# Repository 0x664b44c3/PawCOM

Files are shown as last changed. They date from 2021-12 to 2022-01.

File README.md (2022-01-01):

# PawCOM - a Partyline Analog (Wired) intercom system

## Scope of this project
This projects implements a partyline analog intercom system as used in the tv and event industry for interconnecting small teams of technical staff.

The system consists of any number from 2 up of so-called beltpacks, portable intercom stations plus a central power supply.
The portable parts are interconnected by generic microphone cabling (industry standard) and is electrically compatible to ClearCom, RTS and others.
Analog circuitry was inspired by the classic ClearCom MR102 and others but has been re-engineered from the ground up to use modern components and
add a few extra features.

## PAWCOM features

- analog signal processing with digital control
  - latency free
  - compressor/limiter on mic channel
  - limiter in Rx audio path (your ears will love you)
  - digitally adjustable sidetone level
  - adjustable MIC gain
  - low background noise
- Digital volume control
- digital PTT control with both latching and push to talk mode
- switchable mic power for electred mic headsets
- stereo headphone amp
- optional line in for program audio or personal music player

- click/pop free Call function
  - automatic audible call function if call is held for a certain time

## Circuit description

The beltpack consists of six main components:

- Line receiver 
- Audio mixer and headphone Amp
- Mic preamp and Line driver
- Sidetone Adjust
- Call circuitry
- System control MCU

### Line receiver
The line receiver is based around a quad opamp TL074. One gate implements the line receiver, one gate buffers the sidetone signal, the third gate generates VCC/2 (AGND) which is used througout the line interface. The last gate is unused (connected as a voltage follower with AGND on its input).

### Sidetone circuitry
Sidetone processing is located between the mic preamp (see below) and the line driver.
The sidetone signal is taken from the output of the mic preamp after the tx switch. 
It is then routed through a digital potentiometer MAX5395 and routed through the third opamp of the TL074 were its common mode voltage is translated to AGND (V+/2),
 routed through a passive filter that tries to mimic a typical line impedance, and is then applied to the inverted input of the line receiver OPAMP.

### Mic preamp and Tx switch

The mic preamp is based around an NJM2783 integrated mic preamp that includes
both preamp, switchable gain, a compressor and a buffer amplifier. The mic preamp is powered by a +9V rail generated by a LMR64010 boost converter from the +5V bus (optional, should lower the noise figure of the NJM2783 plus provide a bit more pre-compressor headroom).
The signal is then routed through a TS5A9411 analog switch (capacitive coupling is used here to bring the common mode voltage down to 2.5V) to provide a switchable  additional -10dB pad and then goes into gate 1 of an LMV358 driving 
into the MAX5359 sidetone-digipot.

The Tx signal then goes through a NE5534 driving the signal line. A last bit of filtering is applied here to provide a roll of towards higher frequencies and then driven onto the line through coupling capacitor and a 1.5kΩ resistor.

### Audio mixer

The actual audio mixer section consists of two LMV324 quad-opamps, a DS1881 digital volume control and a NJM2762 compressor/limiter IC.

The signal from the line receiver is goes through the NJM2762 compressor/limiter
and into a TS5A9411 analog switch (line mute).
The signal is then routed through a first buffer stage (gain = 6dB)
and then mixed with the beep signal from the MCU.
This stage drives onto two passive mixers/adders formed by resistor networks
that also provide a place to insert a stereo "program audio" signal into the headphones. This sum-signal is then buffered by two more LMV324 gates and drives the two halves of the DS1881 digital volume control IC.
The output signal of this digipot is buffered once more by two further opamps connected as voltage followers and then finally goes into the headphone amplifier.

### Headphone amplifier

The headphone amplifier is based around a LM4880 stereo amplifier. Currently no
further gain is applied in this stage.
The output goes through two coupling capacitors (100µ electrolytic) and then out to the headset connector. The pins on the headset connector are also connected to ground by 22kΩ resistors to allow the circuitry to reach steady state without connected headphone. This helps to avoid loud clicks upon connection the headset.

### Call circuitry

The call circuitry consists of two parts: call driver and call detector.
The call driver is based around two transistors applying a slew-rate limited, current-limited drive to the signal line of the cable.
Call detection is accomplished by a schmitt trigger built around another gate of a LMV324 with a threshold of roughly 2.5V.

### System controller

An ATMega324PB handles all control tasks in the beltpack. It includes UI (rotary encoder, PTT and call button, a few LEDs), beep tone generation and so on.
Furthermore the uC has one ADC dedicated to monitoring the supply voltage of the beltpack to detect a mic mute pulse as used by some systems.

The digital pots are controlled using an I2C bus that also routes to the front panel (where a PCF8574 port expander takes car eof driving the LEDs and rading PTT and call button status).

## Further reading and other projects about Partyline

You may have a look at the fnordcom project that has compiled a number of schematics and information around
older clearcom intercom systems: https://github.com/pc-coholic/fnordcom

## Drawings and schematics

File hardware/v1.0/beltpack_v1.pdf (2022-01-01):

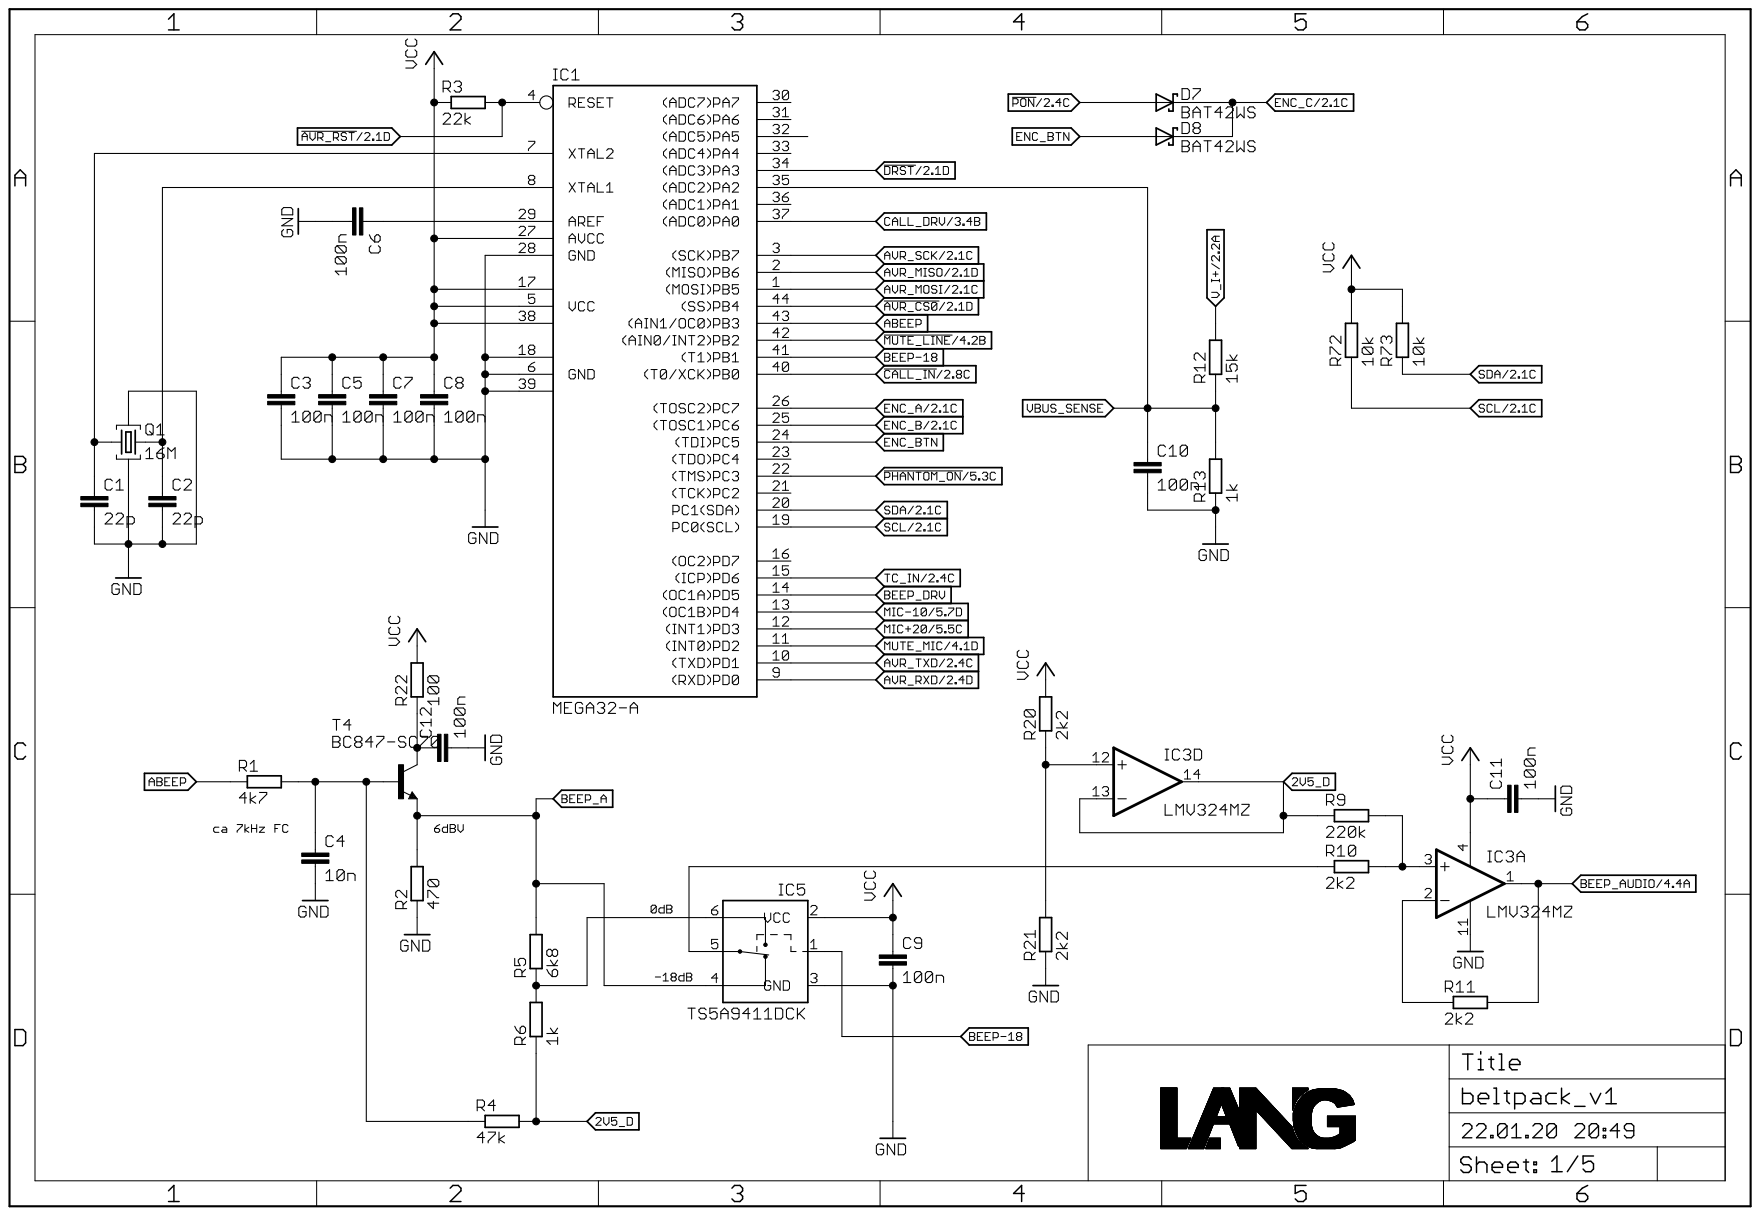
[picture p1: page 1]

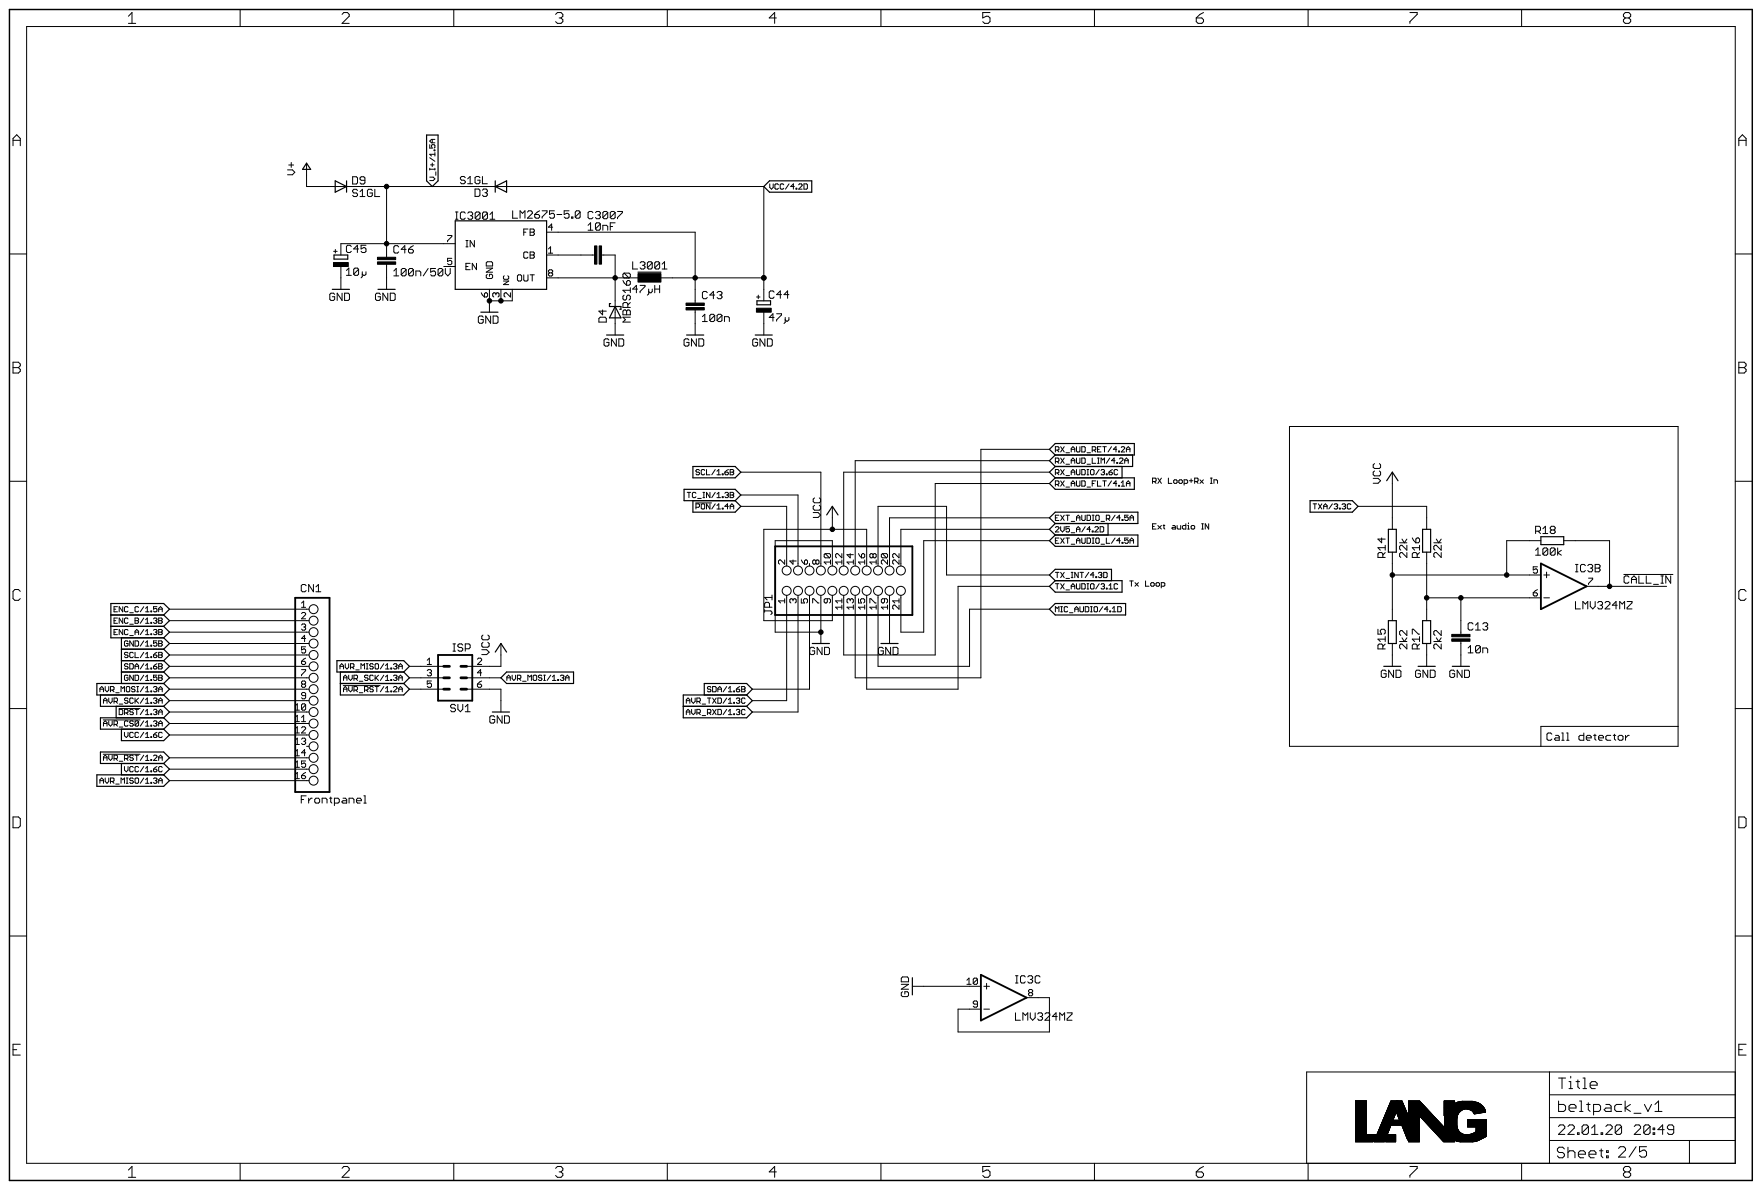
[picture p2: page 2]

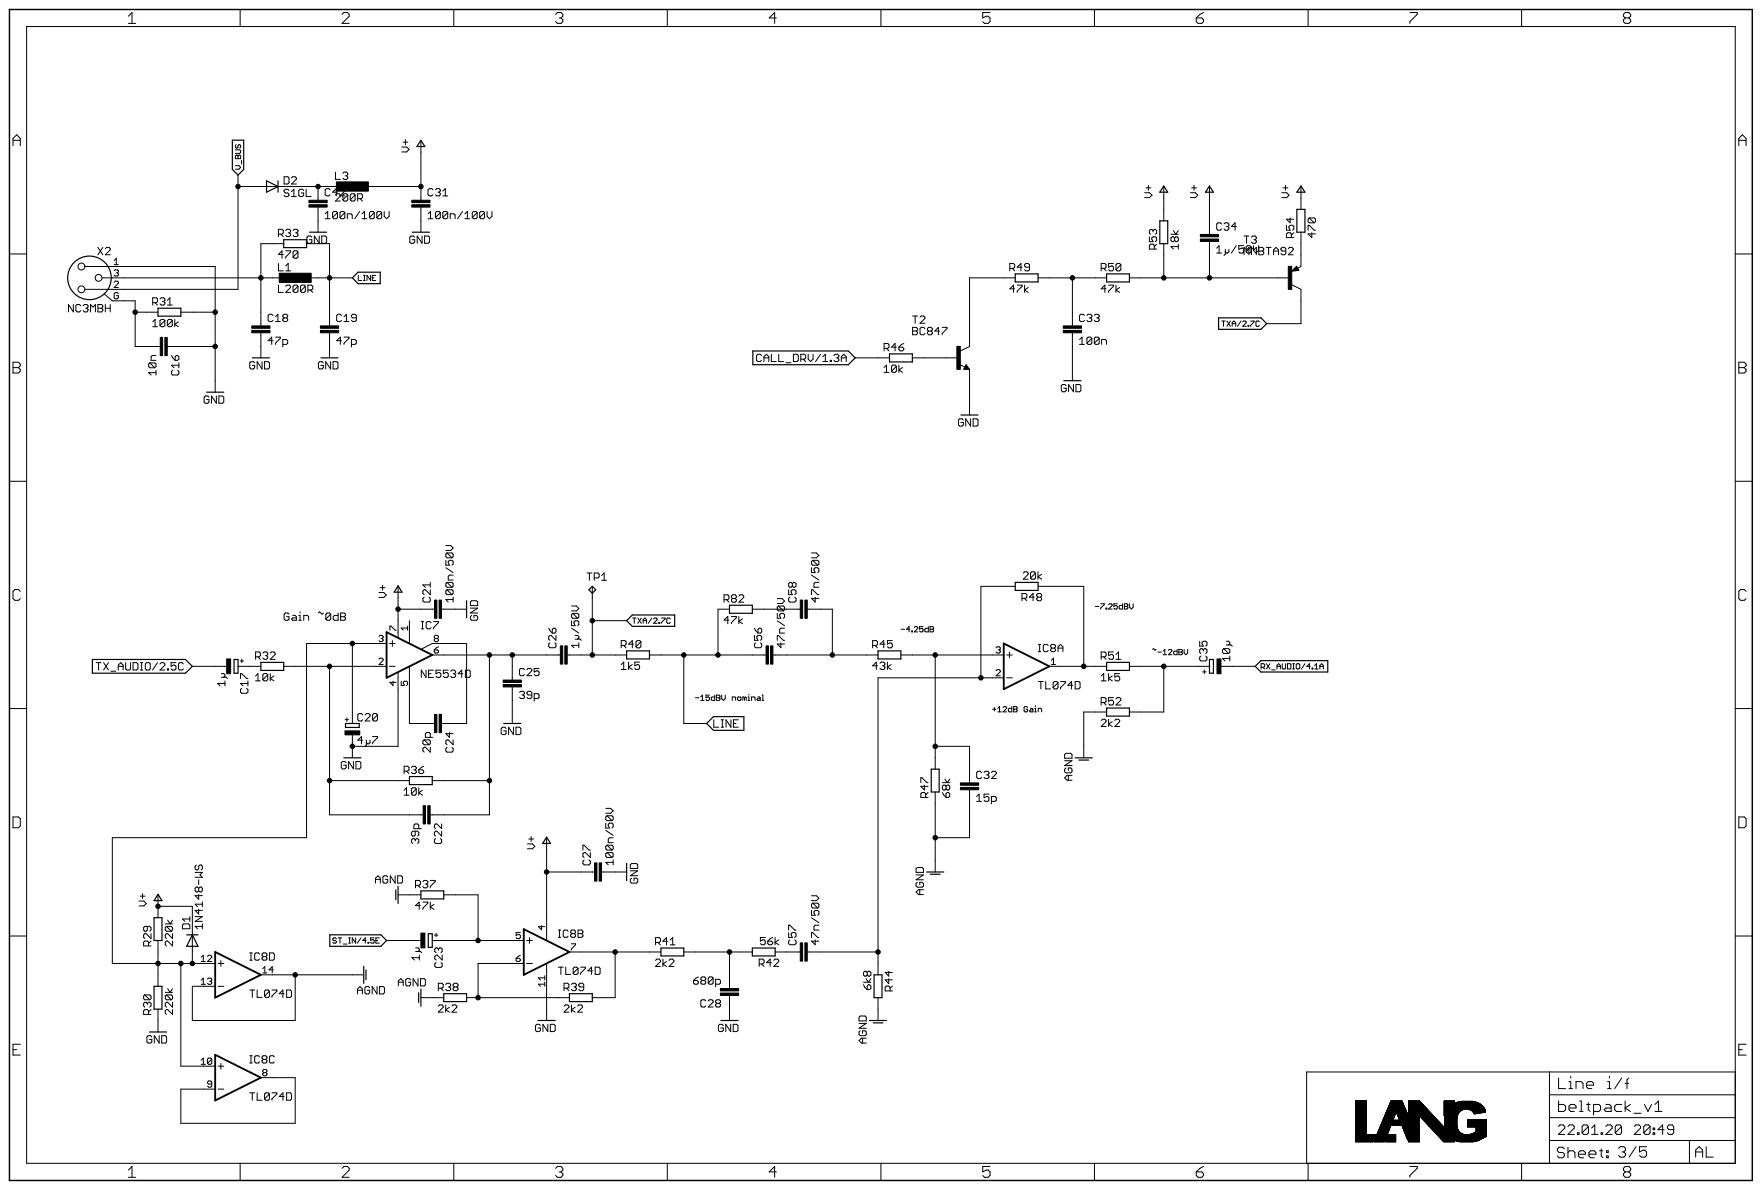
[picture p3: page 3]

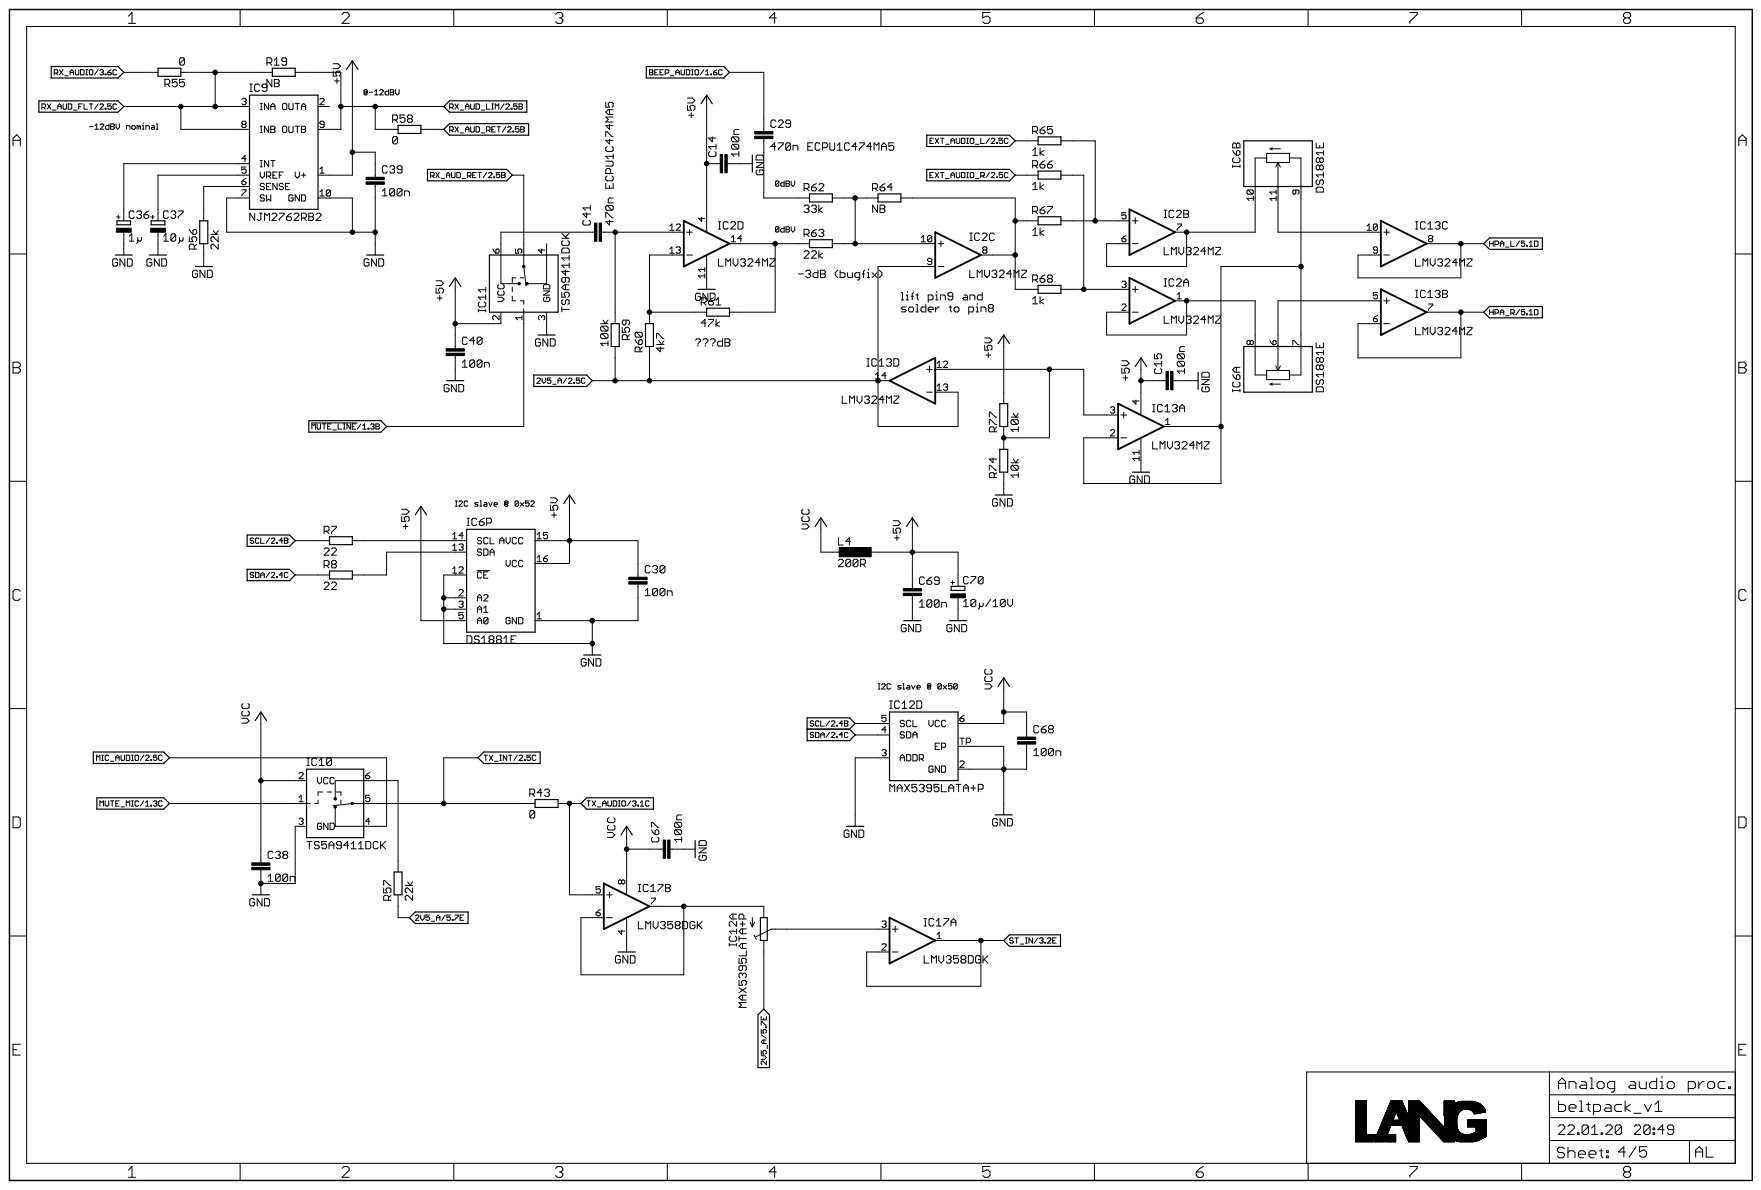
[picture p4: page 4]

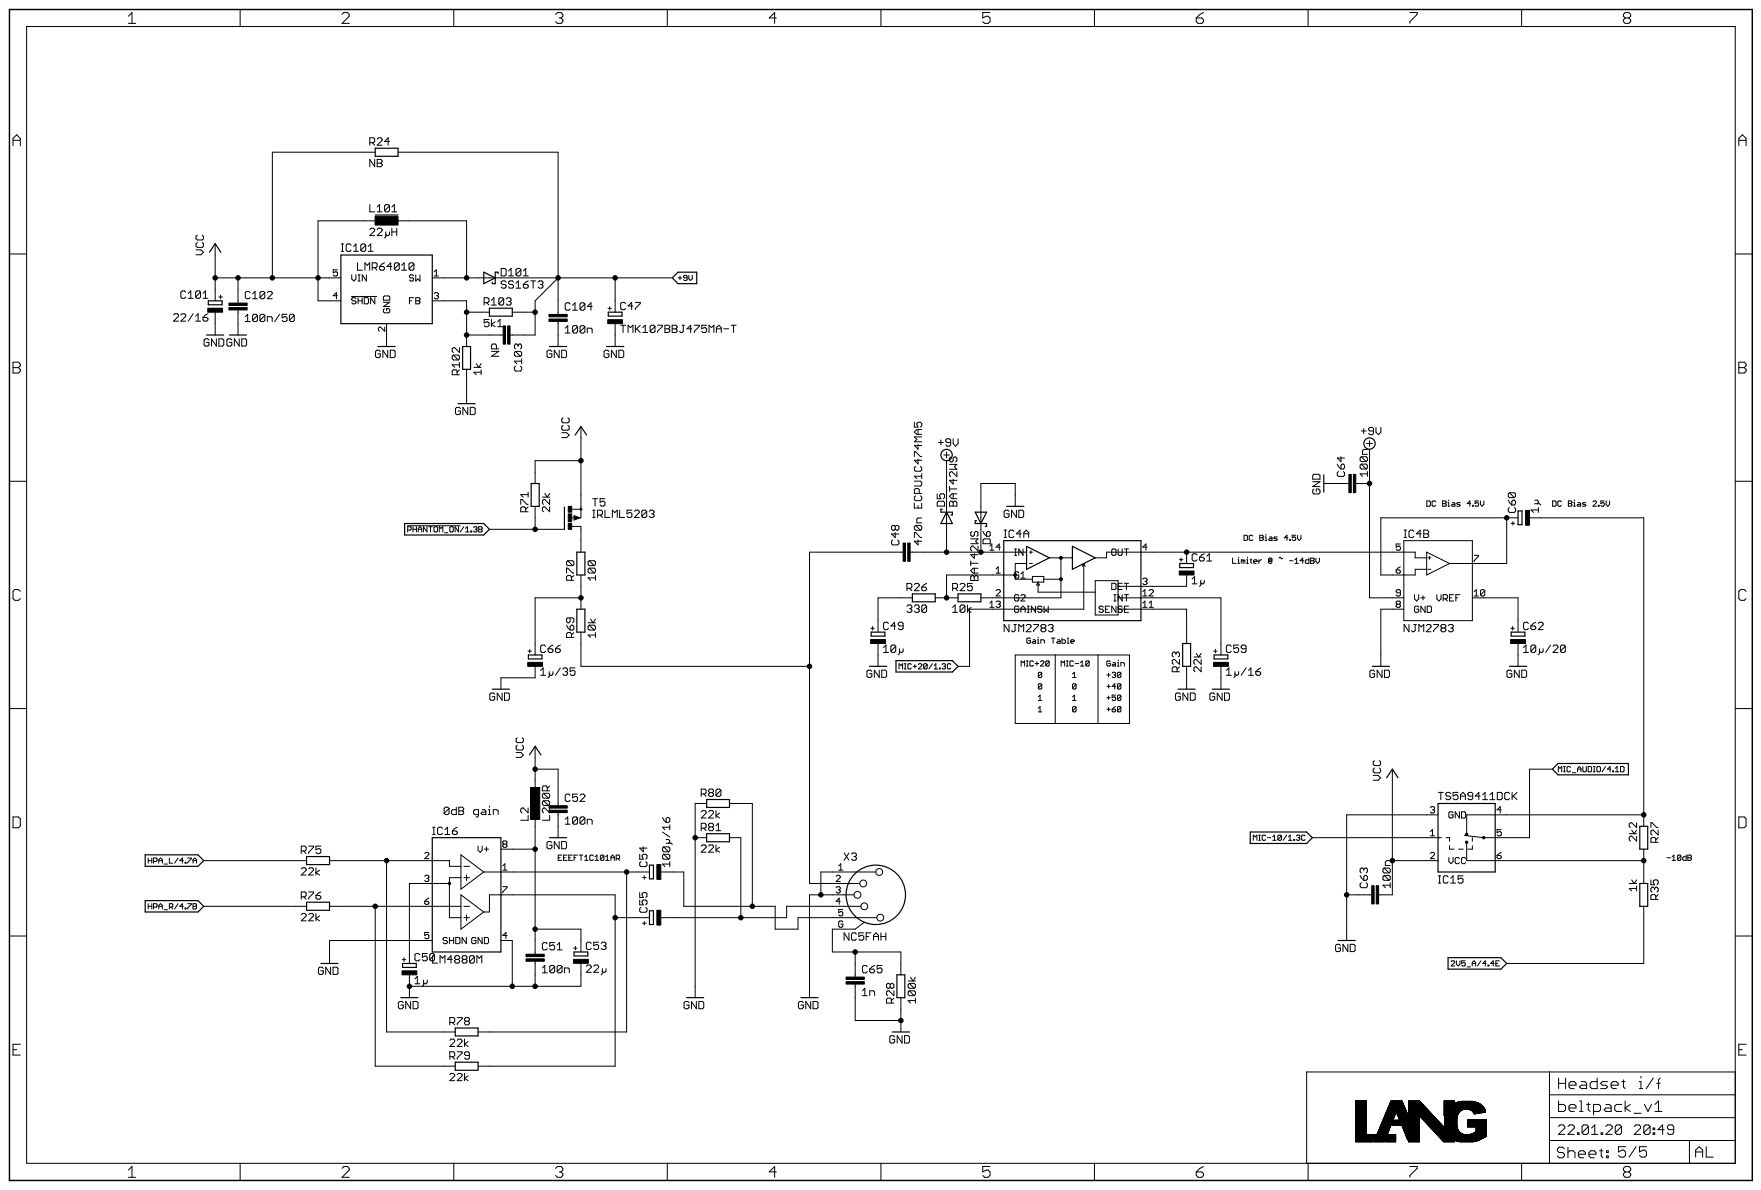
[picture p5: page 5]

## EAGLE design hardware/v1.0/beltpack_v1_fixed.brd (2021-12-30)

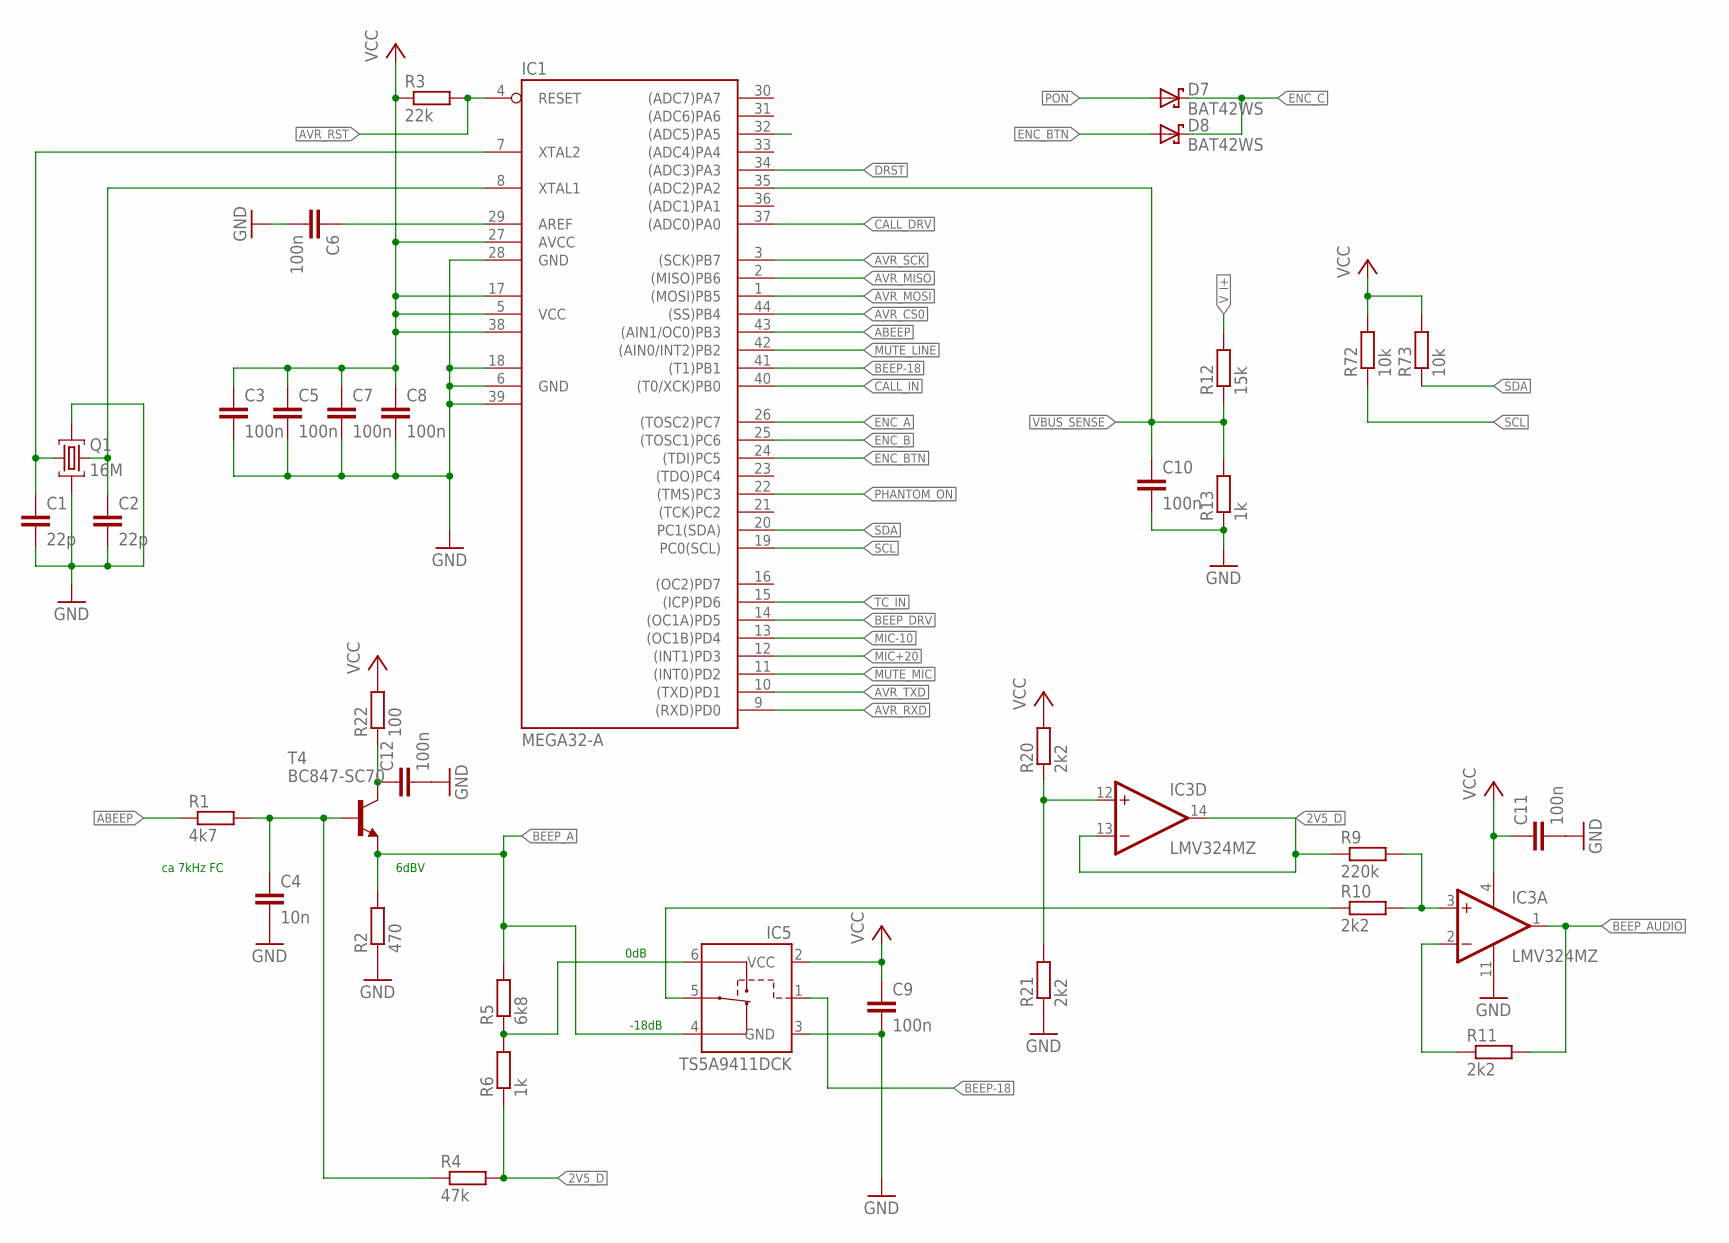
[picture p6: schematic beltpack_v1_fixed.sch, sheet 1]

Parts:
C1, C2: 22p; C0603
C3, C5, C6, C7, C8, C9, C10, C11, C12: 100n; C0603
C4: 10n; C0603
D7, D8: BAT42WS; SOD323R_INFINEON
IC1: MEGA32-A; TQFP44
IC3: LMV324MZ; TSSOP14
IC5: TS5A9411DCK; SC70-6L
Q1: 16M; MT
R1: 4k7; R0603
R2: 470; R0603
R3: 22k; R0603
R4: 47k; R0603
R5: 6k8; R0603
R6, R13: 1k; R0603
R9: 220k; R0603
R10, R11, R20, R21: 2k2; R0603
R12: 15k; R0603
R22: 100; R0603
R72, R73: 10k; R0603
T4: BC847-SC70; SC70

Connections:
2V5_D: IC3.13 (-IN), IC3.14 (OUT), R4.2, R6.1, R9.1
!AVR_CS0!: IC1.44 ((SS)PB4); also elsewhere on the board
!AVR_RST!: IC1.4 (RESET), R3.2; also elsewhere on the board
!CALL_IN!: IC1.40 ((T0/XCK)PB0); also elsewhere on the board
!DRST!: IC1.34 ((ADC3)PA3); also elsewhere on the board
!MUTE_LINE!: IC1.42 ((AIN0/INT2)PB2); also elsewhere on the board
!PHANTOM_ON!: IC1.22 ((TMS)PC3); also elsewhere on the board
!PON!: D7.A; also elsewhere on the board
+5VA: C12.1, R22.1, T4.3 (C)
ABEEP: IC1.43 ((AIN1/OC0)PB3), R1.1
AVR_MISO: IC1.2 ((MISO)PB6); also elsewhere on the board
AVR_MOSI: IC1.1 ((MOSI)PB5); also elsewhere on the board
AVR_RXD: IC1.9 ((RXD)PD0); also elsewhere on the board
AVR_SCK: IC1.3 ((SCK)PB7); also elsewhere on the board
AVR_TXD: IC1.10 ((TXD)PD1); also elsewhere on the board
BEEP-18: IC1.41 ((T1)PB1), IC5.1 (CTL)
BEEP_A: IC5.4 (NC), R2.2, R5.2, T4.2 (E)
BEEP_AUDIO: IC3.1 (OUT), R11.2; also elsewhere on the board
BEEP_DRV: IC1.14 ((OC1A)PD5)
CALL_DRV: IC1.37 ((ADC0)PA0); also elsewhere on the board
ENC_A: IC1.26 ((TOSC2)PC7); also elsewhere on the board
ENC_B: IC1.25 ((TOSC1)PC6); also elsewhere on the board
ENC_BTN: D8.A, IC1.24 ((TDI)PC5)
ENC_C: D7.C (K), D8.C (K); also elsewhere on the board
GND: C1.2, C2.2, C3.2, C4.2, C5.2, C6.2, C7.2, C8.2, C9.2, C10.2, C11.2, C12.2, IC1.6 (GND), IC1.18 (GND1), IC1.28 (GND), IC1.39 (GND2), IC3.11 (V-), IC5.3 (GND), Q1.2 (G1), Q1.4 (G2), R2.1, R13.1, R21.1; also elsewhere on the board
MIC+20: IC1.12 ((INT1)PD3); also elsewhere on the board
MIC-10: IC1.13 ((OC1B)PD4); also elsewhere on the board
MUTE_MIC: IC1.11 ((INT0)PD2); also elsewhere on the board
unnamed: C4.1, R1.2, R4.1, T4.1 (B)
unnamed: IC5.6 (NO), R5.1, R6.2
unnamed: IC3.12 (+IN), R20.1, R21.2
unnamed: IC3.3 (+IN), R9.2, R10.2
unnamed: IC3.2 (-IN), R11.1
unnamed: IC5.5 (COM), R10.1
unnamed: C6.1, IC1.29 (AREF)
unnamed: C1.1, IC1.7 (XTAL2), Q1.1
unnamed: C2.1, IC1.8 (XTAL1), Q1.3 (2)
SCL: IC1.19 (PC0(SCL)), R72.1; also elsewhere on the board
SDA: IC1.20 (PC1(SDA)), R73.1; also elsewhere on the board
TC_IN: IC1.15 ((ICP)PD6); also elsewhere on the board
VBUS_SENSE: C10.1, IC1.35 ((ADC2)PA2), R12.1, R13.2
VCC: C3.1, C5.1, C7.1, C8.1, C9.1, C11.1, IC1.5 (VCC), IC1.17 (VCC1), IC1.27 (AVCC), IC1.38 (VCC2), IC3.4 (V+), IC5.2 (VCC), R3.1, R20.2, R22.2, R72.2, R73.2; also elsewhere on the board
V_I+: R12.2; also elsewhere on the board

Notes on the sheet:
ca 7kHz FC
0dB
-18dB
6dBV

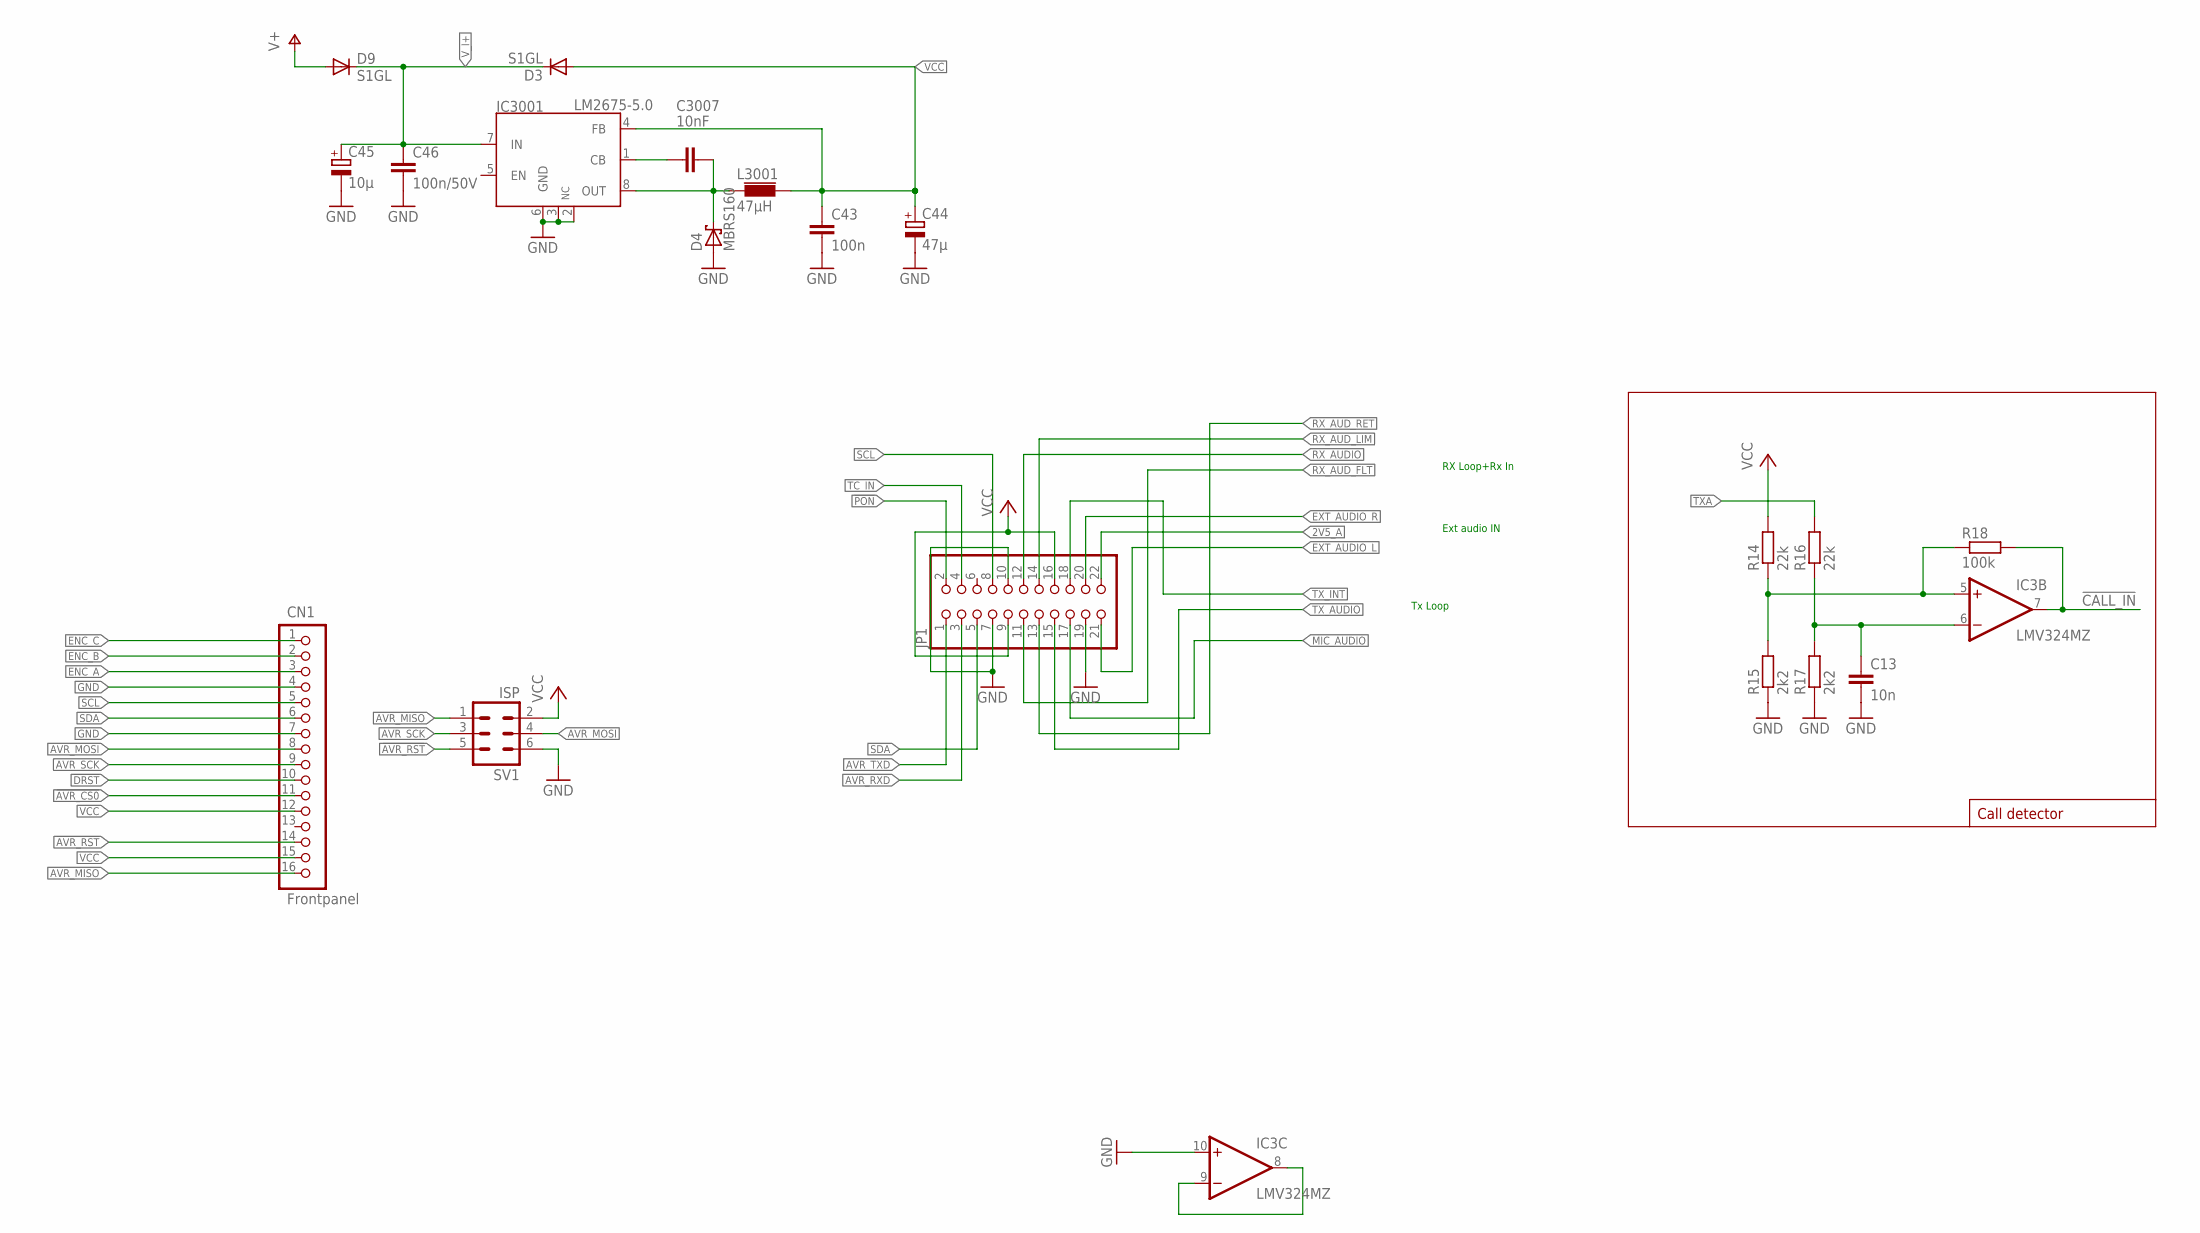
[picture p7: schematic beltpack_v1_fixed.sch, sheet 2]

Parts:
C13: 10n; C0603
C43: 100n; C0603
C44: 47µ; PANASONIC_B
C45: 10µ; PANASONIC_C
C46: 100n/50V; C0805
C3007: 10nF; C0805
CN1: Frontpanel; MOLEX-505278-1633
D3, D9: S1GL; DO219AB
D4: MBRS160; SMB
IC3: LMV324MZ; TSSOP14
IC3001: LM2675-5.0; SO-08
JP1: PINHD-2X11; 2X11
L3001: 47µH; PISM
R14, R16: 22k; R0603
R15, R17: 2k2; R0603
R18: 100k; R0603
SV1: ISP; ML6

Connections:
2V5_A: JP1.22; also elsewhere on the board
!AVR_CS0!: CN1.11; also elsewhere on the board
!AVR_RST!: CN1.14, SV1.5; also elsewhere on the board
!CALL_IN!: IC3.7 (OUT), R18.2; also elsewhere on the board
!DRST!: CN1.10; also elsewhere on the board
!PON!: JP1.2; also elsewhere on the board
AVR_MISO: CN1.16, SV1.1; also elsewhere on the board
AVR_MOSI: CN1.8, SV1.4; also elsewhere on the board
AVR_RXD: JP1.3; also elsewhere on the board
AVR_SCK: CN1.9, SV1.3; also elsewhere on the board
AVR_TXD: JP1.1; also elsewhere on the board
ENC_A: CN1.3; also elsewhere on the board
ENC_B: CN1.2; also elsewhere on the board
ENC_C: CN1.1; also elsewhere on the board
EXT_AUDIO_L: JP1.21; also elsewhere on the board
EXT_AUDIO_R: JP1.20; also elsewhere on the board
GND: C13.2, C43.2, C44.-, C45.-, C46.2, CN1.4, CN1.7, D4.A, IC3.10 (+IN), IC3001.2 (NC), IC3001.3 (NC), IC3001.6 (GND), JP1.7, JP1.10, JP1.19, R15.1, R17.1, SV1.6; also elsewhere on the board
MIC_AUDIO: JP1.17; also elsewhere on the board
unnamed: C3007.2, D4.C, IC3001.8 (OUT), L3001.P$1
unnamed: C3007.1, IC3001.1 (CB)
unnamed: IC3.8 (OUT), IC3.9 (-IN)
unnamed: C13.1, IC3.6 (-IN), R16.1, R17.2
unnamed: IC3.5 (+IN), R14.1, R15.2, R18.1
RX_AUDIO: JP1.12; also elsewhere on the board
RX_AUD_FLT: JP1.11; also elsewhere on the board
RX_AUD_LIM: JP1.14; also elsewhere on the board
RX_AUD_RET: JP1.13; also elsewhere on the board
SCL: CN1.5, JP1.8; also elsewhere on the board
SDA: CN1.6, JP1.5; also elsewhere on the board
TC_IN: JP1.4; also elsewhere on the board
TXA: R16.2; also elsewhere on the board
TX_AUDIO: JP1.15; also elsewhere on the board
TX_INT: JP1.18; also elsewhere on the board
V+: D9.A; also elsewhere on the board
VCC: C43.1, C44.+, CN1.12, CN1.15, D3.A, IC3001.4 (FB), JP1.9, JP1.16, L3001.P$2, R14.2, SV1.2; also elsewhere on the board
V_I+: C45.+, C46.1, D3.C, D9.C, IC3001.7 (IN); also elsewhere on the board

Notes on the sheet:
Call detector
Ext audio IN
RX Loop+Rx In
Tx Loop

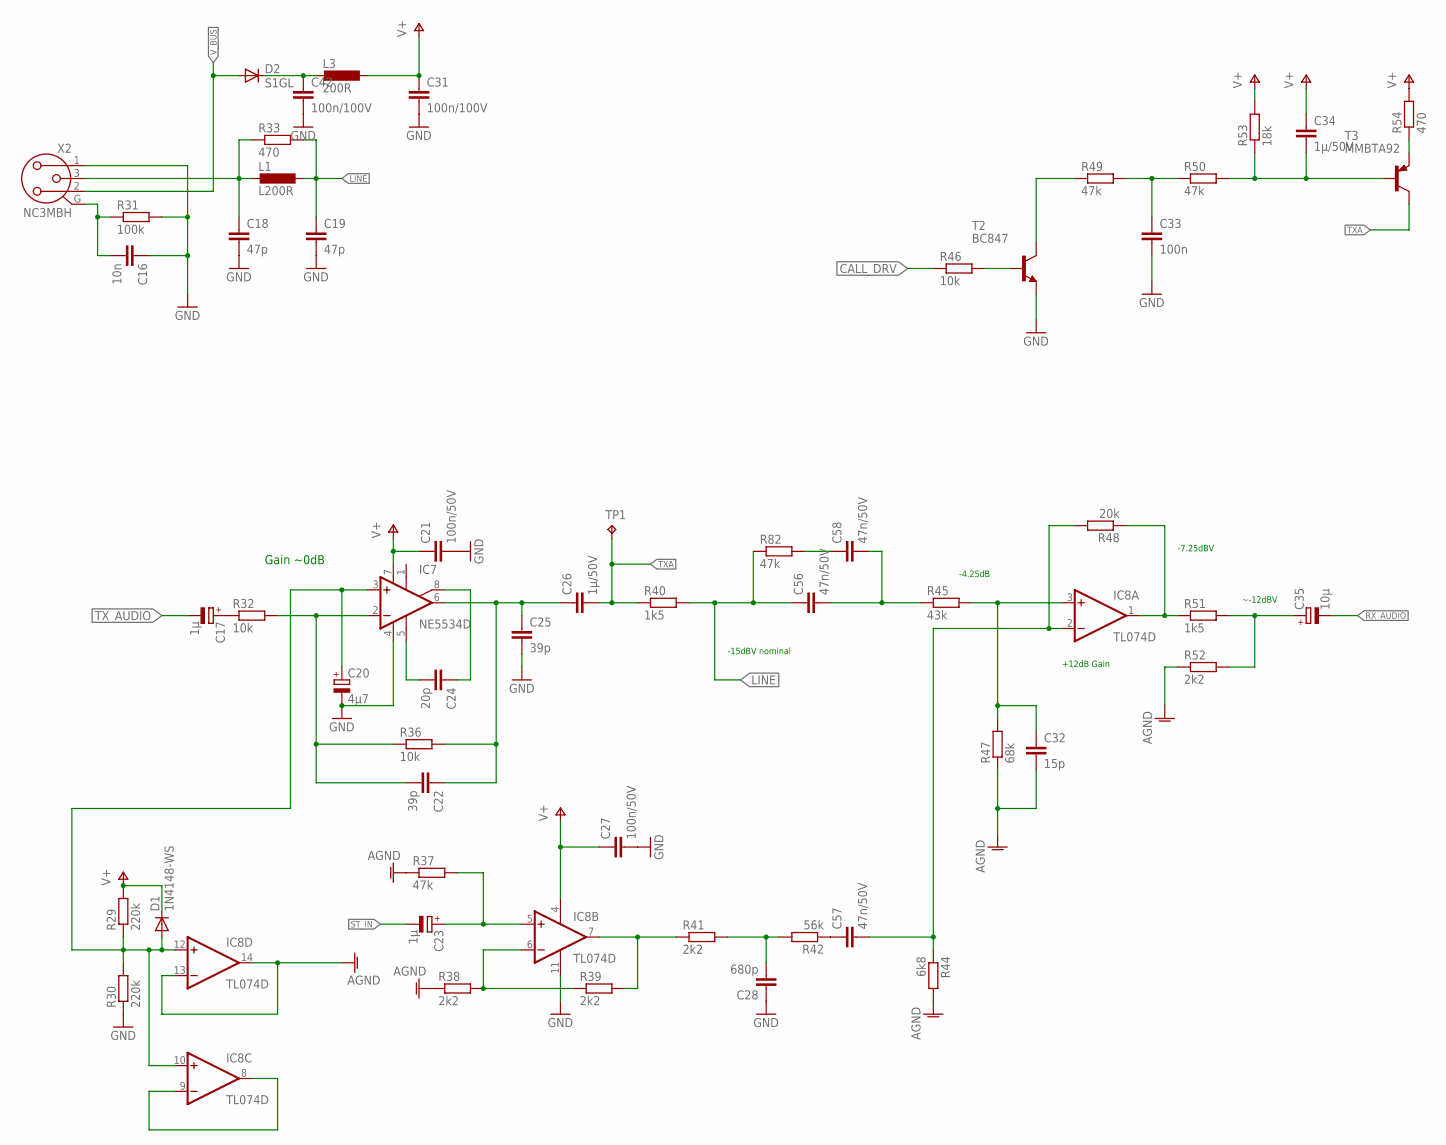
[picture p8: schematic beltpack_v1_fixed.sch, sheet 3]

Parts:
C16: 10n; C0805
C17, C23: 1µ; PANASONIC_B
C18, C19: 47p; C0603
C20: 4µ7; PANASONIC_B
C21, C27: 100n/50V; C0805
C22, C25: 39p; C0603
C24: 20p; C0603
C26, C34: 1µ/50V; C1206
C28: 680p; C0603
C31, C42: 100n/100V; C1206
C32: 15p; C0603
C33: 100n; C0603
C35: 10µ; PANASONIC_B
C56, C57, C58: 47n/50V; C_PAN_ECHU_E1
D1: 1N4148-WS; SOD323
D2: S1GL; DO219AB
IC7: NE5534D; SO08
IC8: TL074D; SO14
L1: L200R; R0805
L3: 200R; R0805
R29, R30: 220k; R0603
R31: 100k; R0805
R32, R36, R46: 10k; R0603
R33: 470; R0603
R37, R49, R50, R82: 47k; R0603
R38, R39, R41, R52: 2k2; R0603
R40: 1k5; R1206
R42: 56k; R0603
R44: 6k8; R0603
R45: 43k; R0603
R47: 68k; R0603
R48: 20k; R0603
R51: 1k5; R0603
R53: 18k; R0603
R54: 470; R0805
T2: BC847; SOT23
T3: MMBTA92; SOT23
TP1: XA; B1,27
X2: NC3MBH

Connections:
AGND: C32.2, IC8.13 (-IN), IC8.14 (OUT), R37.1, R38.1, R44.2, R47.1, R52.1
CALL_DRV: R46.1; also elsewhere on the board
GND: C16.1, C18.2, C19.2, C20.-, C21.2, C25.2, C27.2, C28.1, C31.2, C33.2, C42.2, IC7.4 (V-), IC8.11 (V-), R30.1, R31.2, T2.2 (E), X2.1; also elsewhere on the board
LINE: C19.1, C56.1, L1.1, R33.2, R40.2, R82.1
unnamed: C24.2, IC7.5 (CMP)
unnamed: C24.1, IC7.8 (ON/CMP)
unnamed: C22.2, IC7.2 (-IN), R32.2, R36.1
unnamed: C17.+, R32.1
unnamed: C22.1, C25.1, C26.1, IC7.6 (OUT), R36.2
unnamed: C20.+, D1.A, IC7.3 (+IN), IC8.10 (+IN), IC8.12 (+IN), R29.1, R30.2
unnamed: R46.2, T2.1 (B)
unnamed: C16.2, R31.1, X2.G
unnamed: C58.1, R82.2
unnamed: C28.2, R41.2, R42.2
unnamed: C32.1, IC8.3 (+IN), R45.2, R47.2
unnamed: C18.1, L1.2, R33.1, X2.3
unnamed: C35.+, R51.2, R52.2
unnamed: C57.2, IC8.2 (-IN), R44.1, R48.2
unnamed: C57.1, R42.1
unnamed: C42.1, D2.C, L3.2
unnamed: C56.2, C58.2, R45.1
unnamed: R54.1, T3.2 (E)
unnamed: C34.2, R50.2, R53.1, T3.1 (B)
unnamed: C33.1, R49.2, R50.1
unnamed: R49.1, T2.3 (C)
unnamed: IC8.1 (OUT), R48.1, R51.1
unnamed: IC8.7 (OUT), R39.2, R41.1
unnamed: IC8.6 (-IN), R38.2, R39.1
unnamed: C23.+, IC8.5 (+IN), R37.2
unnamed: IC8.8 (OUT), IC8.9 (-IN)
RX_AUDIO: C35.-; also elsewhere on the board
ST_IN: C23.-; also elsewhere on the board
TXA: C26.2, R40.1, T3.3 (C), TP1.TP; also elsewhere on the board
TX_AUDIO: C17.-; also elsewhere on the board
V+: C21.1, C27.1, C31.1, C34.1, D1.K (C), IC7.7 (V+), IC8.4 (V+), L3.1, R29.2, R53.2, R54.2; also elsewhere on the board
V_BUS: D2.A, X2.2

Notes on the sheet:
-15dBV nominal
+12dB Gain
-4.25dB
-7.25dBV
~-12dBV
Gain ~0dB

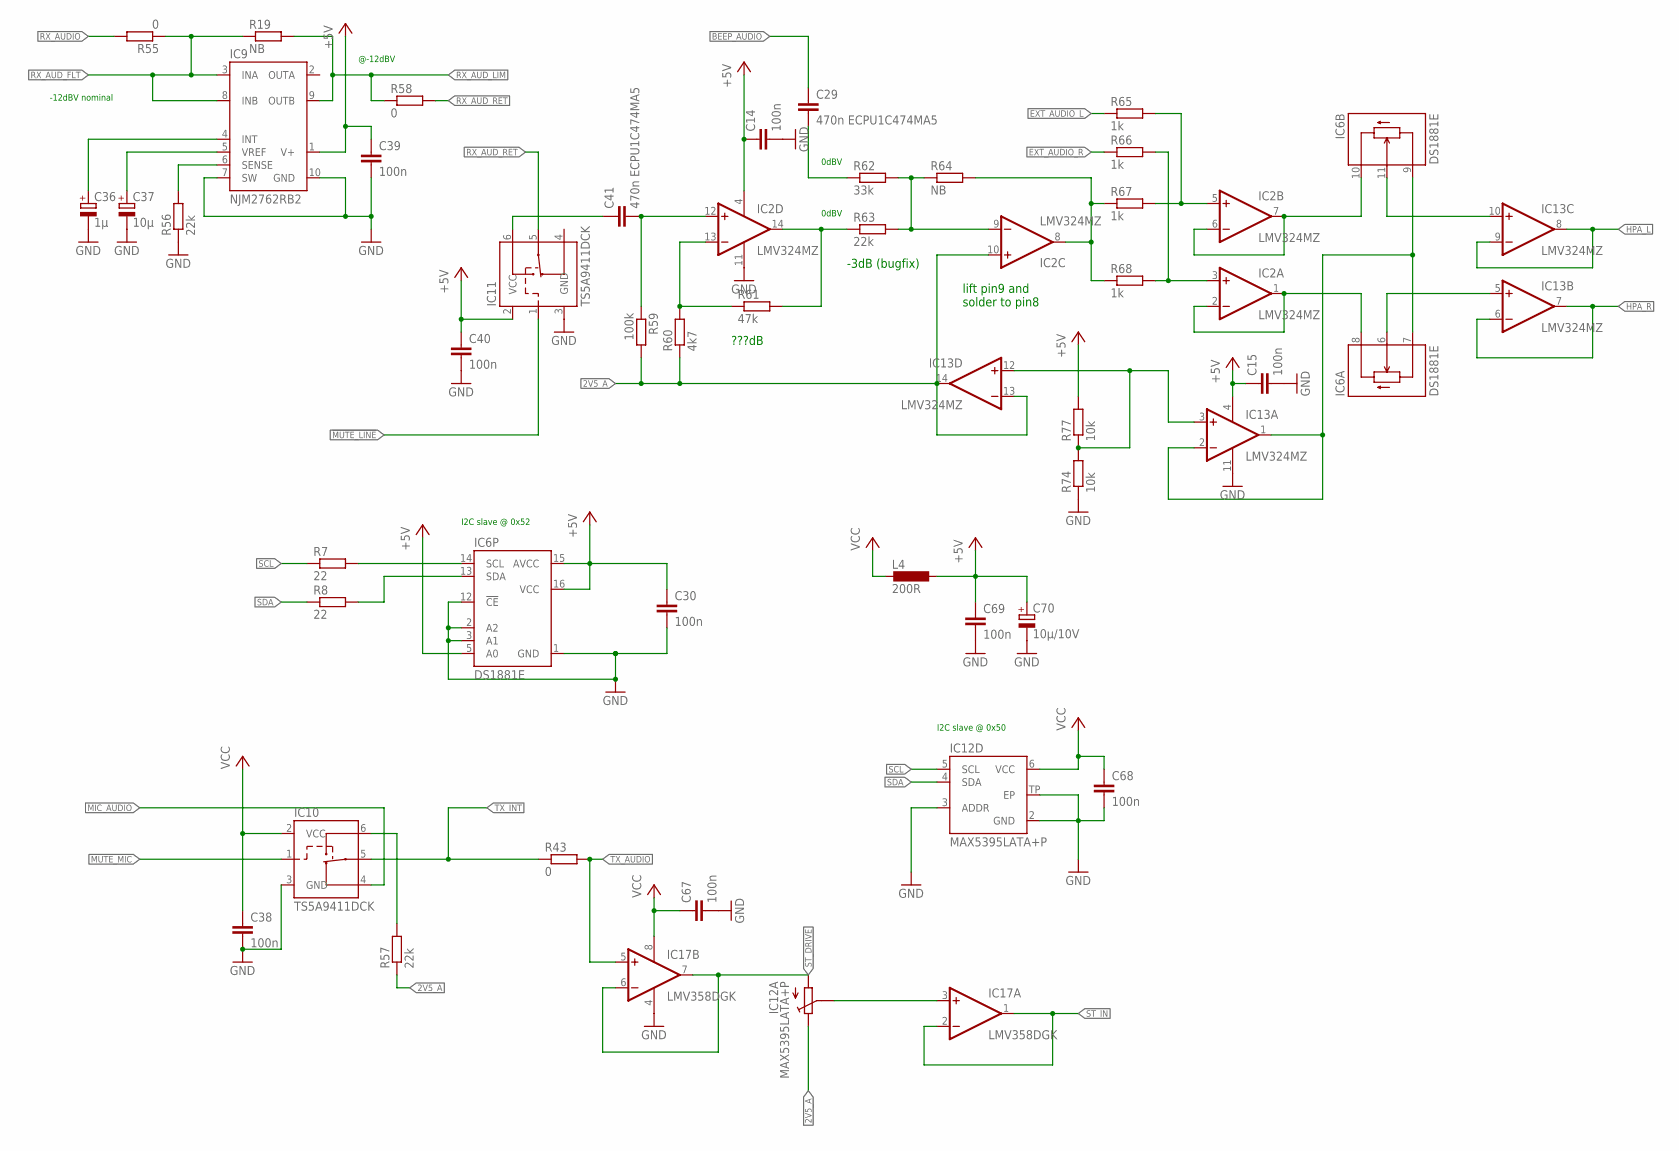
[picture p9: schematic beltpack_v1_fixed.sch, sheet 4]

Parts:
C14, C15, C30, C39, C40, C67, C68, C69: 100n; C0603
C29, C41: 470n ECPU1C474MA5; C_PANASONIC_H3
C36: 1µ; PANASONIC_B
C37: 10µ; PANASONIC_B
C38: 100n; C0402
C70: 10µ/10V; A/3216-18R
IC2, IC13: LMV324MZ; TSSOP14
IC6: DS1881E; TSSOP16
IC9: NJM2762RB2; MSOP10
IC10, IC11: TS5A9411DCK; SC70-6L
IC12: MAX5395LATA+P; 8TDFN-EP
IC17: LMV358DGK; VSOP8
L4: 200R; R0805
R7, R8: 22; R0402
R19, R64: NB; R0603
R43, R55, R58: 0; R0603
R56, R57, R63: 22k; R0603
R59: 100k; R0603
R60: 4k7; R0603
R61: 47k; R0603
R62: 33k; R0603
R65, R66, R67, R68: 1k; R0603
R74, R77: 10k; R0603

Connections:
2V5_A: IC2.10 (+IN), IC12.8 (E), IC13.13 (-IN), IC13.14 (OUT), R57.1, R59.2, R60.1; also elsewhere on the board
!MUTE_LINE!: IC11.1 (CTL); also elsewhere on the board
+5V: C14.1, C15.1, C30.1, C39.1, C40.1, C69.1, C70.+, IC2.4 (V+), IC6.5 (A0), IC6.15 (AVCC), IC6.16 (VCC), IC9.1 (V+), IC11.2 (VCC), IC13.4 (V+), L4.1, R77.2
BEEP_AUDIO: C29.1; also elsewhere on the board
EXT_AUDIO_L: R65.1; also elsewhere on the board
EXT_AUDIO_R: R66.1; also elsewhere on the board
GND: C14.2, C15.2, C30.2, C36.-, C37.-, C38.2, C39.2, C40.2, C67.2, C68.2, C69.2, C70.-, IC2.11 (V-), IC6.1 (GND), IC6.2 (A2), IC6.3 (A1), IC6.12 (!CE!), IC9.7 (SW), IC9.10 (GND), IC10.3 (GND), IC11.3 (GND), IC12.2 (GND), IC12.3 (ADDR), IC12.TP (EP), IC13.11 (V-), IC17.4 (V-), R56.1, R74.1; also elsewhere on the board
HPA_L: IC13.8 (OUT), IC13.9 (-IN); also elsewhere on the board
HPA_R: IC13.6 (-IN), IC13.7 (OUT); also elsewhere on the board
MIC_AUDIO: IC10.4 (NC); also elsewhere on the board
MIX_L: IC2.6 (-IN), IC2.7 (OUT), IC6.10 (H)
MIX_R: IC2.1 (OUT), IC2.2 (-IN), IC6.8 (H)
MUTE_MIC: IC10.1 (CTL); also elsewhere on the board
unnamed: IC6.11 (W), IC13.10 (+IN)
unnamed: IC6.6 (W), IC13.5 (+IN)
unnamed: IC6.14 (SCL), R7.2
unnamed: IC6.13 (SDA), R8.2
unnamed: IC6.7 (L), IC6.9 (L), IC13.1 (OUT), IC13.2 (-IN)
unnamed: IC13.3 (+IN), IC13.12 (+IN), R74.2, R77.1
unnamed: C29.2, R62.1
unnamed: C41.1, IC11.6 (NO)
unnamed: IC2.13 (-IN), R60.2, R61.1
unnamed: C36.+, IC9.4 (INT)
unnamed: C37.+, IC9.5 (VREF)
unnamed: IC2.14 (OUT), R61.2, R63.1
unnamed: IC9.6 (SENSE), R56.2
unnamed: C41.2, IC2.12 (+IN), R59.1
unnamed: IC2.9 (-IN), R62.2, R63.2, R64.1
unnamed: IC2.8 (OUT), R64.2, R67.1, R68.1
unnamed: IC2.5 (+IN), R65.2, R67.2
unnamed: IC2.3 (+IN), R66.2, R68.2
unnamed: IC10.6 (NO), R57.2
unnamed: IC12.7 (S), IC17.3 (+IN)
RX_AUDIO: R55.2; also elsewhere on the board
RX_AUD_FLT: IC9.3 (INA), IC9.8 (INB), R19.1, R55.1; also elsewhere on the board
RX_AUD_LIM: IC9.9 (OUTB), R19.2, R58.1; also elsewhere on the board
RX_AUD_RET: IC11.5 (COM), R58.2; also elsewhere on the board
SCL: IC12.5 (SCL), R7.1; also elsewhere on the board
SDA: IC12.4 (SDA), R8.1; also elsewhere on the board
ST_DRIVE: IC12.1 (A), IC17.6 (-IN), IC17.7 (OUT)
ST_IN: IC17.1 (OUT), IC17.2 (-IN); also elsewhere on the board
TX_AUDIO: IC17.5 (+IN), R43.2; also elsewhere on the board
TX_INT: IC10.5 (COM), R43.1; also elsewhere on the board
VCC: C38.1, C67.1, C68.1, IC10.2 (VCC), IC12.6 (VCC), IC17.8 (V+), L4.2; also elsewhere on the board

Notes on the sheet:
0dBV
@-12dBV
-12dBV nominal
I2C slave @ 0x50
I2C slave @ 0x52
lift pin9 and solder to pin8
???dB
-3dB (bugfix)

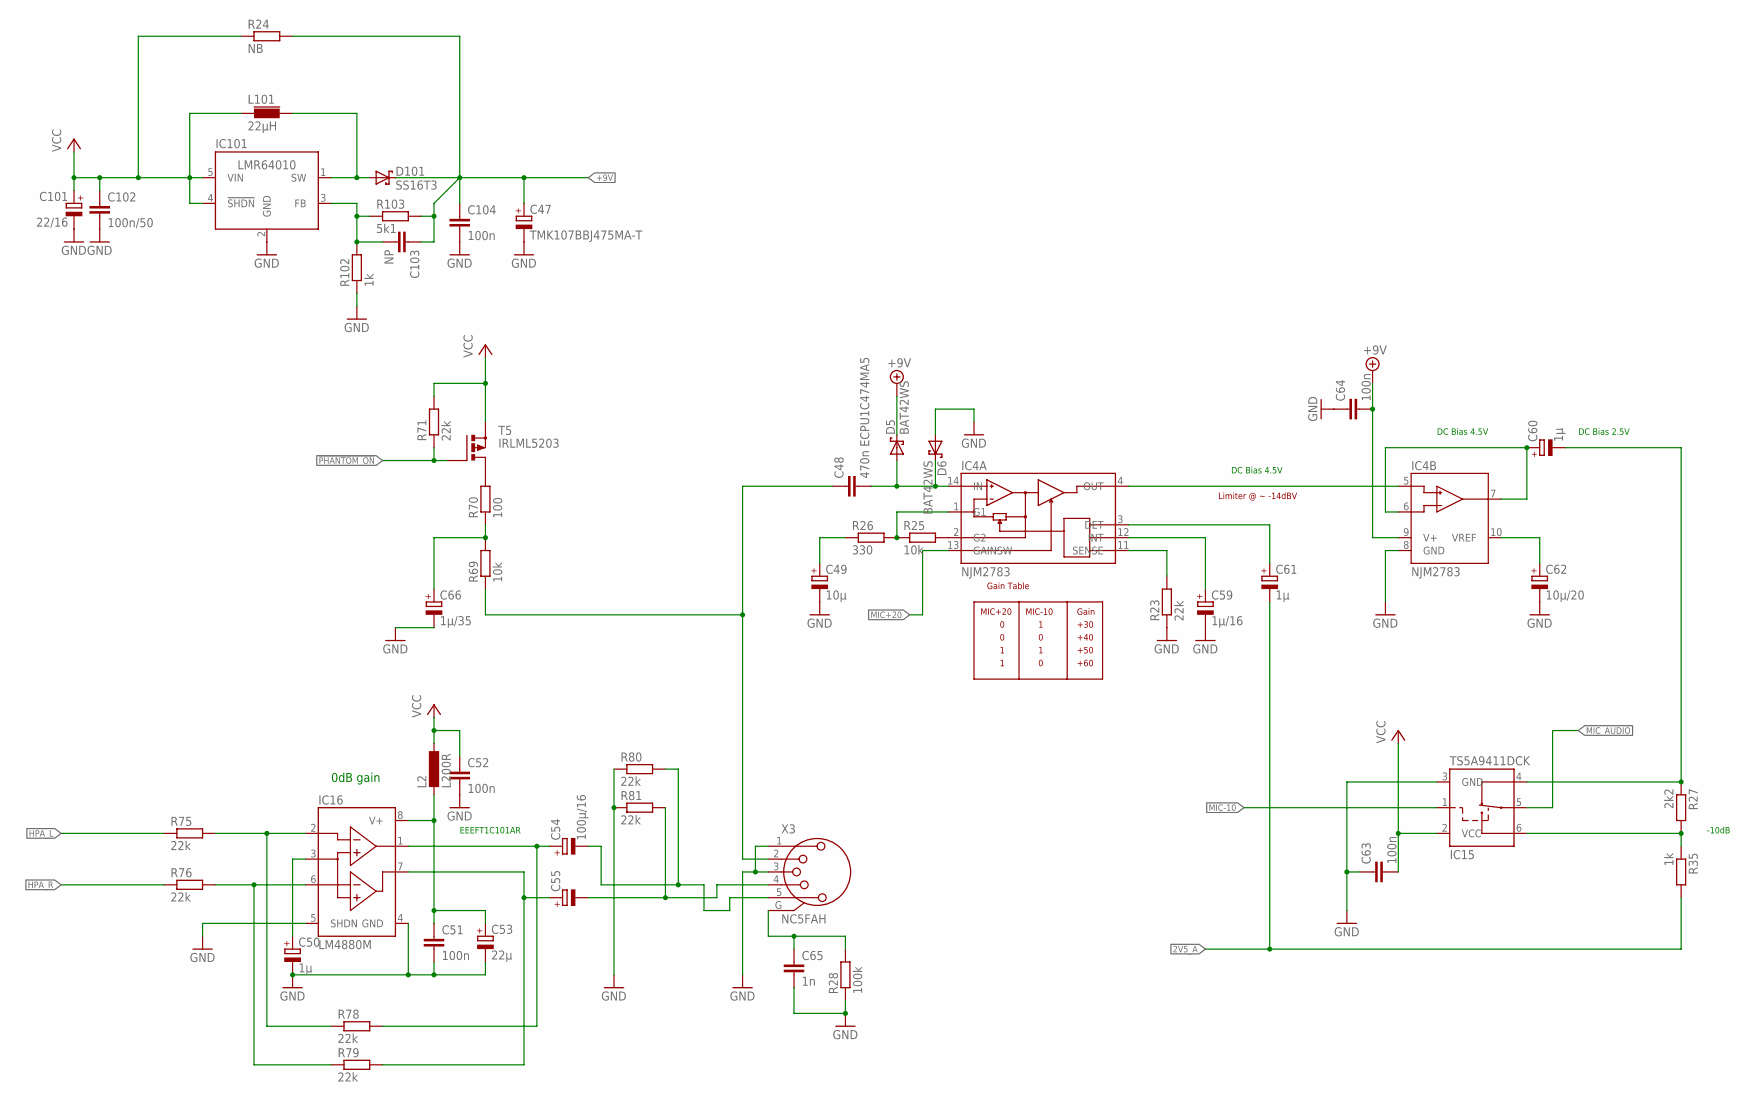
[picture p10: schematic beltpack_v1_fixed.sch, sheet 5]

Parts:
C47: TMK107BBJ475MA-T; PANASONIC_B
C48: 470n ECPU1C474MA5; C_PANASONIC_H3
C49: 10µ; PANASONIC_B
C50, C60, C61: 1µ; PANASONIC_B
C51, C52, C64, C104: 100n; C0603
C53: 22µ; PANASONIC_C
C54, C55: 100µ/16; PANASONIC_C
C59: 1µ/16; A/3216-18R
C62: 10µ/20; B/3528-21R
C63: 100n; C0402
C65: 1n; C0603
C66: 1µ/35; B/3528-21R
C101: 22/16; B/3528-21R
C102: 100n/50; C0805
C103: NP; C0603
D5, D6: BAT42WS; SOD323R_INFINEON
D101: SS16T3; SMA
IC4: NJM2783; TSSOP14
IC15: TS5A9411DCK; SC70-6L
IC16: LM4880M; SOIC8
IC101: LMR64010; SOT23-5
L2: L200R; R0805
L101: 22µH; PISG
R23, R71, R75, R76, R78, R79, R80, R81: 22k; R0603
R24: NB; R0603
R25, R69: 10k; R0603
R26: 330; R0603
R27: 2k2; R0603
R28: 100k; R0603
R35, R102: 1k; R0603
R70: 100; R0603
R103: 5k1; R0603
T5: IRLML5203; SOT23
X3: NC5FAH

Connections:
2V5_A: C61.-, R35.2; also elsewhere on the board
!PHANTOM_ON!: R71.1, T5.1 (G); also elsewhere on the board
+9V: C47.+, C64.2, C103.1, C104.1, D5.C (K), D101.C (K), IC4.9 (V+), R24.2, R103.2
GND: C47.-, C49.-, C50.-, C51.2, C52.2, C53.-, C59.-, C62.-, C63.1, C64.1, C65.2, C66.-, C101.-, C102.2, C104.2, D6.A, IC4.8 (GND), IC15.3 (GND), IC16.4 (GND), IC16.5 (SHDN), IC101.2 (GND), R23.1, R28.1, R80.1, R81.1, R102.1, X3.1, X3.3; also elsewhere on the board
HPA_L: R75.1; also elsewhere on the board
HPA_R: R76.1; also elsewhere on the board
MIC: C48.1, R69.1, X3.2
MIC+20: IC4.13 (GAINSW); also elsewhere on the board
MIC-10: IC15.1 (CTL); also elsewhere on the board
MIC_AUDIO: IC15.5 (COM); also elsewhere on the board
unnamed: C54.+, IC16.1 (OUTA), R78.2
unnamed: C55.+, IC16.7 (OUTB), R79.2
unnamed: C103.2, IC101.3 (FB), R102.2, R103.1
unnamed: C55.-, R81.2, X3.4
unnamed: C54.-, R80.2, X3.5
unnamed: C50.+, IC16.3 (BYPASS)
unnamed: C48.2, D5.A, D6.C (K), IC4.14 (IN)
unnamed: IC4.2 (G2), R25.2
unnamed: IC4.1 (G1), R25.1, R26.2
unnamed: C49.+, R26.1
unnamed: C59.+, IC4.12 (INT)
unnamed: C65.1, R28.2, X3.G
unnamed: C51.1, C53.+, IC16.8 (V+), L2.2
unnamed: C61.+, IC4.3 (DET)
unnamed: IC4.4 (OUT), IC4.5 (BUFIN)
unnamed: IC4.11 (SENSE), R23.2
unnamed: C60.+, IC4.6 (BUFG), IC4.7 (BUFO)
unnamed: IC15.6 (NO), R27.2, R35.1
unnamed: C66.+, R69.2, R70.1
unnamed: C60.-, IC15.4 (NC), R27.1
unnamed: C62.+, IC4.10 (VREF)
unnamed: R70.2, T5.3 (D)
unnamed: IC16.6 (INB), R76.2, R79.1
unnamed: IC16.2 (INA), R75.2, R78.1
SW_HV: D101.A, IC101.1 (SW), L101.P$2
VCC: C52.1, C63.2, C101.+, C102.1, IC15.2 (VCC), IC101.4 (!SHDN!), IC101.5 (VIN), L2.1, L101.P$1, R24.1, R71.2, T5.2 (S); also elsewhere on the board

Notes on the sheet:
EEEFT1C101AR
DC Bias 4.5V
DC Bias 2.5V
-10dB
Gain Table
MIC+20
MIC-10
Gain
+30
+40
+50
+60
Limiter @ ~ -14dBV
0dB gain

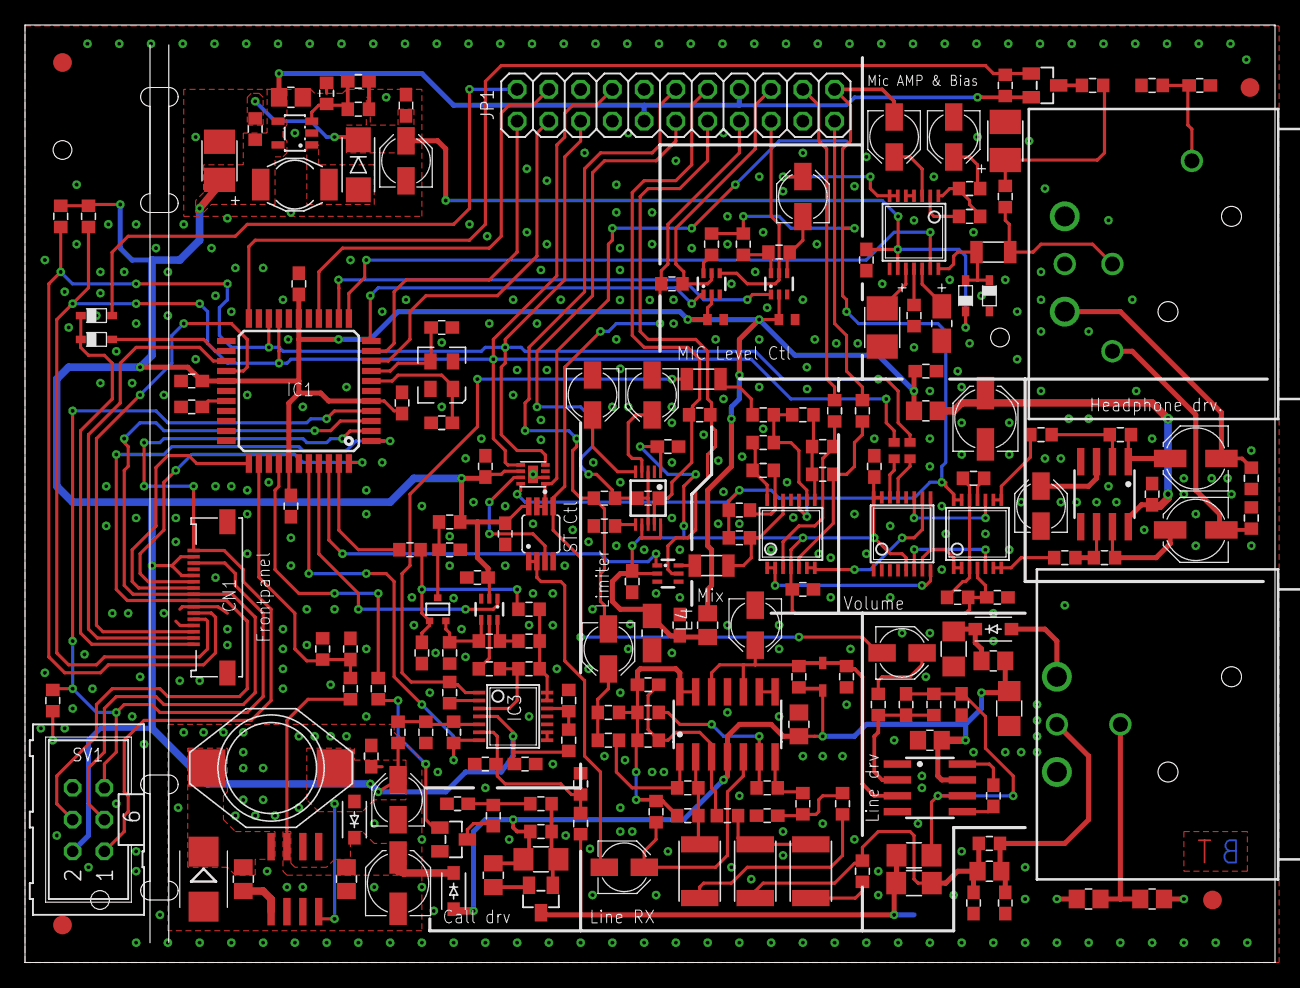
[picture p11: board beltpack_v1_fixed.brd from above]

Board: 2 copper layers, 100.0 x 75.0 mm, 207 parts (1 on the bottom side), 142 nets.

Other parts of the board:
U$1, U$2, U$3, U$4: FIDUCIAL_G15

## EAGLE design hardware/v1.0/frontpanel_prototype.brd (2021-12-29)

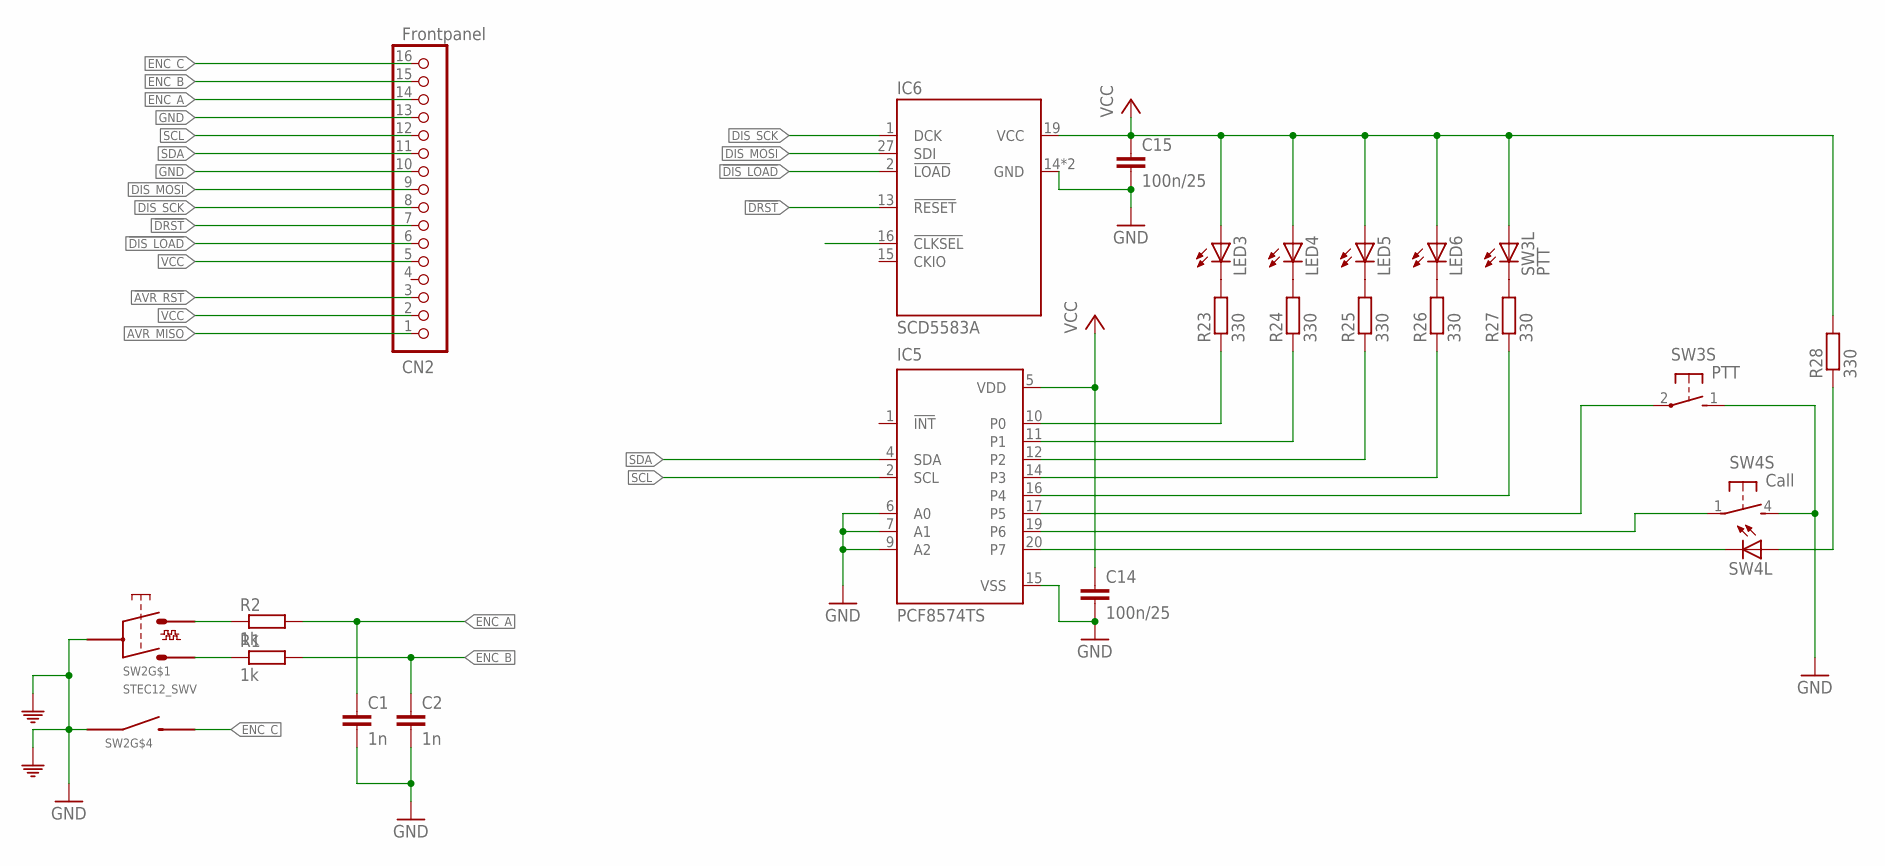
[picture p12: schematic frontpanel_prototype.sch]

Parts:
C1, C2: 1n; C0603
C14, C15: 100n/25; C0603
CN2: Frontpanel; MOLEX-505278-1633
IC5: PCF8574TS; SSOP20
IC6: SCD5583A; SCD558XA
LED3, LED4, LED5, LED6: LEDLZR181; LZR181
R1, R2: 1k; R0603
R23, R24, R25, R26, R27, R28: 330; R0603
SW2: STEC12_SWV; STEC12_VERT
SW3: PTT; 6425
SW4: Call; MEC_5G_LED

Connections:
!AVR_RST!: CN2.3
!DIS_LOAD!: CN2.6, IC6.2 (!LOAD!)
!DRST!: CN2.7, IC6.13 (!RESET!)
AVR_MISO: CN2.1
DIS_MOSI: CN2.9, IC6.27 (SDI)
DIS_SCK: CN2.8, IC6.1 (DCK)
ENC_A: C1.1, CN2.14, R2.2
ENC_B: C2.1, CN2.15, R1.2
ENC_C: CN2.16, SW2.Y
GND: C1.2, C2.2, C14.2, C15.2, CN2.10, CN2.13, IC5.6 (A0), IC5.7 (A1), IC5.9 (A2), IC5.15 (VSS), IC6.14 (GND), IC6.28 (GND), SW2.B, SW2.G1, SW2.G2, SW2.X, SW3.1 (S), SW4.4 (S)
unnamed: R2.1, SW2.A
unnamed: R1.1, SW2.C
unnamed: R27.2, SW3.K (C)
unnamed: LED3.K (C), R23.2
unnamed: R28.1, SW4.3 (A)
unnamed: IC5.19 (P6), SW4.1
unnamed: IC5.20 (P7), SW4.2 (C)
unnamed: IC5.17 (P5), SW3.2
unnamed: LED4.K (C), R24.2
unnamed: LED5.K (C), R25.2
unnamed: LED6.K (C), R26.2
unnamed: IC5.16 (P4), R27.1
unnamed: IC5.10 (P0), R23.1
unnamed: IC5.11 (P1), R24.1
unnamed: IC5.12 (P2), R25.1
unnamed: IC5.14 (P3), R26.1
SCL: CN2.12, IC5.2 (SCL)
SDA: CN2.11, IC5.4 (SDA)
VCC: C14.1, C15.1, CN2.2, CN2.5, IC5.5 (VDD), IC6.19 (VCC), LED3.A, LED4.A, LED5.A, LED6.A, R28.2, SW3.A

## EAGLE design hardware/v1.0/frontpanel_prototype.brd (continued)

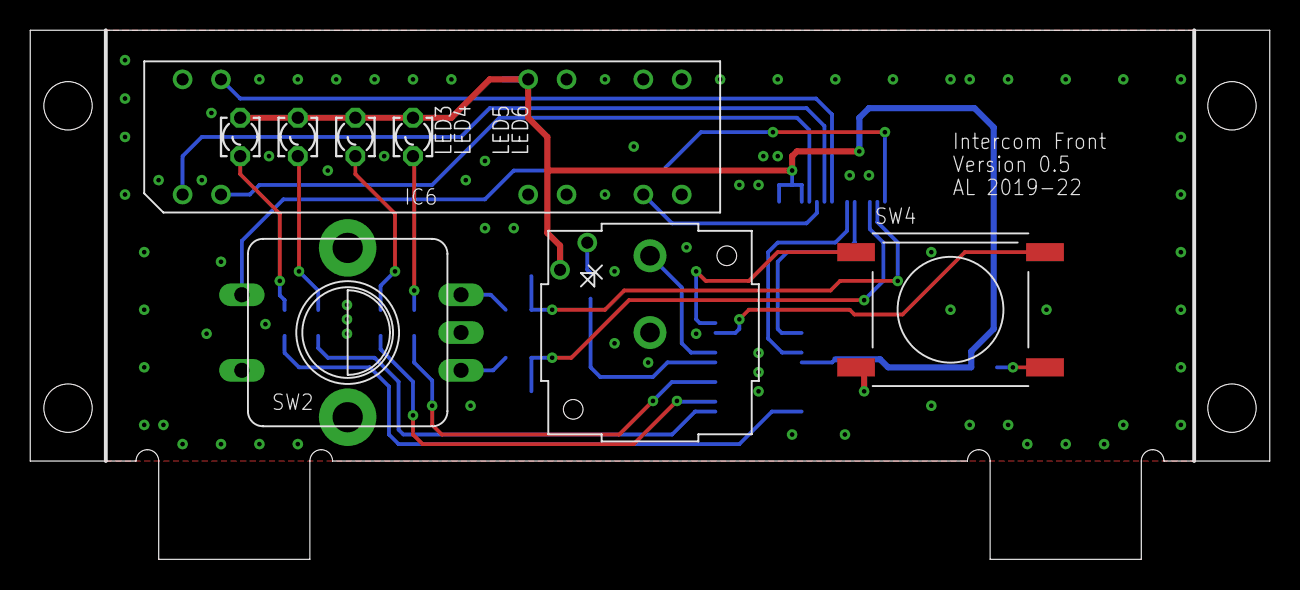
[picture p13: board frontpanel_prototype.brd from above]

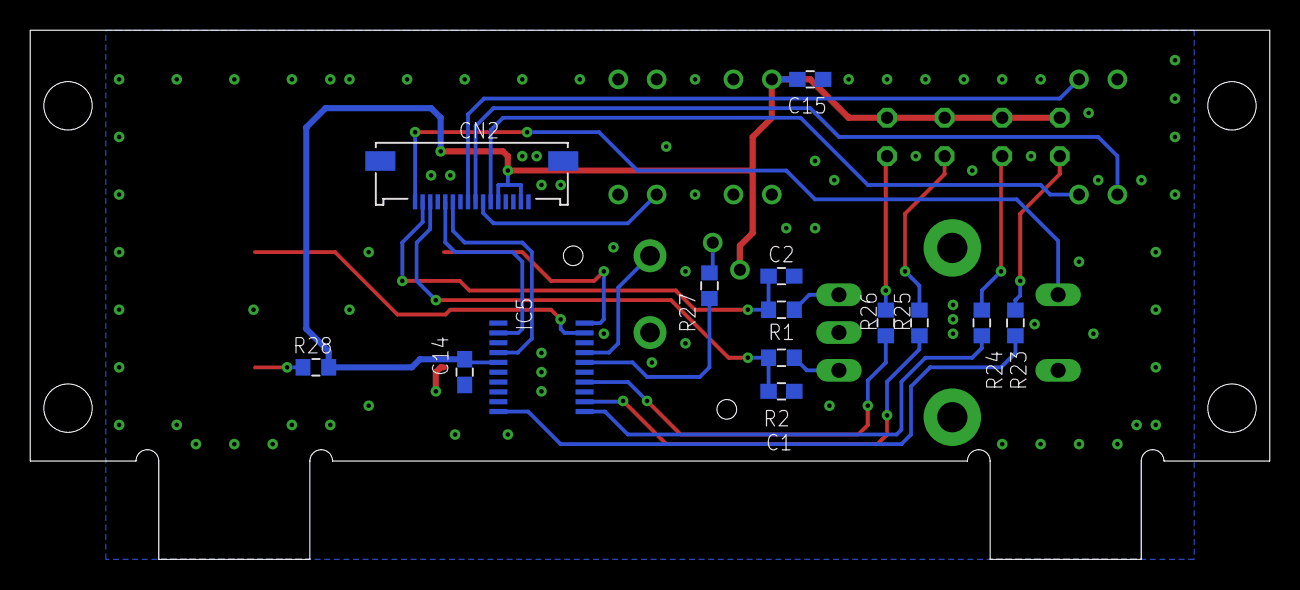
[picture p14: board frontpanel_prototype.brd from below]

Board: 2 copper layers, 82.0 x 35.0 mm, 22 parts (14 on the bottom side), 27 nets.

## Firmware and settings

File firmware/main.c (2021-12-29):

#include <string.h>
#include <inttypes.h>
#include <avr/interrupt.h>
#include <avr/eeprom.h>
#include <util/delay.h>
#include <stdio.h>
#include "i2c.h"
#include "gptimer.h"
#include "buttons.h"
#include "hardware.h"
#include "crc.h"

typedef union {
	uint16_t u16;
	struct {
		uint8_t u8l;
		uint8_t u8h;
	};
} accu_t;

enum pcfBits {
	frontLED1 = 0x01,
	frontLED2 = 0x02,
	frontLED3 = 0x04,
	frontLED4 = 0x08,
	frontLEDs = 0x0f,
	frontLEDPtt = 0x10,
	frontBtnPtt = 0x20,
	frontBtnCall= 0x40,
	frontLedCall= 0x80u,
	frontOuputMask=0x9fu
};


#define MENU_HOLD_TIME 10000

//countdown counter for call lamp
uint8_t call_sig=0;

//tone duration timer
uint8_t tmr_tones=TMR_INVALID;
//call signalling timneout
uint8_t tmr_call_delay=TMR_INVALID;
//beeper mode
uint8_t tone_mode = 0;


extern volatile uint8_t tone_inc;
void signalling_task(void)
{
	if (tmr_tones == TMR_INVALID)
		tmr_tones = timer_reg();
	if (tmr_call_delay == TMR_INVALID)
		tmr_call_delay = timer_reg();

	if (call_in)
	{
		call_sig = 16;
		mute_line = 0;

		if (timer_expired(tmr_call_delay))
		{
			tones_queued = 0;
			if (tone_mode==0)
			{
				beep_setvol(sysCfg.call_vol);
				tone_inc=32;
				timer_set(tmr_tones, 125);
				tone_mode=1;
			}
			else
			{
				if (timer_expired(tmr_tones))
				{
					beep_setvol(sysCfg.call_vol);
					timer_set(tmr_tones, 125);
					tone_inc=32-tone_inc;
				}
			}
		}
	}
	else
	{
		timer_set(tmr_call_delay, 3000);
		if (tone_mode)
			timer_set(tmr_tones, 0);

		tone_mode=0;

		if (!tones_queued)
		{
			if (timer_expired(tmr_tones))
				tone_inc=0;
		}
		else
		{
			if (timer_expired(tmr_tones))
			{
				if (toneQueue[0].volume!=0xff)
					beep_setvol(toneQueue[0].volume);
				uint32_t inc = toneQueue[0].freq;
				if (inc)
				{
					inc*=256;
					inc/=16000;
					tone_inc = inc;
				}
				else
					tone_inc = 0;
				timer_set(tmr_tones, toneQueue[0].duration);
				for(uint8_t i=0; i<7;++i)
					toneQueue[i] = toneQueue[i+1];
				--tones_queued;
			}
		}
	}

}

uint8_t enc_old=0;
enum
{
	lvlVolume=0,
	lvlSideTone=1,
	lvlMicGain=2
};
uint8_t menu_level = lvlVolume;

uint8_t tmr_menuEscape = TMR_INVALID;

uint8_t old_btn_press=0;
uint8_t tmr_btn_press = 0xff;

void save_config( void )
{
	sysCfg.crc = crc8(&sysCfg, sizeof(struct configBlock) - 1);
	eeprom_write_block(&sysCfg, (void*) 0x10, sizeof(struct configBlock));
}

void menu_finish( void )
{
	push_tone(1,800, 100, 10);
	push_tone(0,600, 100, 10);
	menu_level = lvlVolume;
	save_config();
}


void encoder_task(void)
{
	if (TMR_INVALID == tmr_btn_press)
	{
		tmr_btn_press = timer_reg();
	}

	int8_t delta = enc_ctr - enc_old;

	if ((menu_level != lvlVolume) && (delta))
		timer_set(tmr_menuEscape, MENU_HOLD_TIME);

	switch (menu_level) {
		case lvlVolume:
			if (delta)
			{
				mute_line = 0;
				update_gpio();
			}
			if (delta > 0)
			{
				if (sysCfg.volume < 31)
				{
					++sysCfg.volume;
					update_volume();
					push_tone(1,2000,15,9);
				}
				else
				{
					push_tone(1,500,50,9);
					push_tone(0,  0,20,9);
					push_tone(0,500,50,9);
				}
			}
			if (delta < 0)
			{
				if (sysCfg.volume > 0)
				{
					--sysCfg.volume;
					update_volume();
					push_tone(1,2000,15,9);
				}
				else
				{
					push_tone(1,250,50,9);
					push_tone(0,  0,20,9);
					push_tone(0,250,50,9);
				}
			}
			break;
		case lvlSideTone:
			if (delta)
			{
				if ((delta > 0) && (sysCfg.sidetone<15))
				{
					sysCfg.sidetone++;
				}
				if ((delta < 0) && (sysCfg.sidetone>0))
				{
					sysCfg.sidetone--;
				}
				update_sidetone();
				push_tone(1,2000,15,9);
			}
			break;
		case lvlMicGain:
			if (delta)
			{
				if ((delta > 0) && (sysCfg.mic_gain_and_pwr & cfgMicGainMask) < 3)
				{
					sysCfg.mic_gain_and_pwr++;
				}
				if ((delta < 0) && (sysCfg.mic_gain_and_pwr & cfgMicGainMask) >0)
				{
					sysCfg.mic_gain_and_pwr--;
				}
				push_tone(1,2000,15,9);
			}
		default:
			break;
	}
	enc_old = enc_ctr;

}

typedef enum {
	tgt_pcfFrontWrite = 0,
	tgt_pcfFrontQuery,
	tgt_pcfFrontRead,
	tgt_ds1881,
	tgt_max5395,
	tgtEnd
} twi_target_t;

twi_target_t twi_target = tgt_pcfFrontWrite;


uint8_t twi_buffer[3];
uint8_t twi_tasksel=0;
uint8_t front_out=0xff;
uint8_t front_inp=0xff;
void i2c_task(void)
{
	if (!__twi_ready())
		return;
	switch (twi_tasksel)
	{
		case tgt_pcfFrontWrite:
			twi_buffer[0] = (front_out | (~frontOuputMask));
			_twi_send_data(0x40, twi_buffer, 1);
			twi_tasksel = tgt_pcfFrontQuery;
			break;
		case tgt_pcfFrontQuery:
			_twi_read_data(0x40, twi_buffer, 1);
			twi_tasksel = tgt_pcfFrontRead;
			break;
		case tgt_pcfFrontRead:
			front_inp = twi_buffer[0];
			twi_tasksel = tgt_pcfFrontWrite;
			break;
	}
}


int main(void) {

	uint8_t buffer[8];
	init_hw();
	init_timers();
	init_beep();
	_i2c_init();

	tmr_menuEscape = timer_reg();

	sei();

	_delay_ms(1);

	buffer[0] = 0x80;
	buffer[1] = 0x9c;
	_twi_send_data(0x50, buffer, 2);
	__twi_wait_ready();
	buffer[0] = 0x00;
	buffer[1] = 0xff;
	_twi_send_data(0x50, buffer, 2);
	__twi_wait_ready();
	buffer[0] = 0x00 | 0x1f;
	buffer[1] = 0x40 | 0x1f;
	buffer[2] = 0x84;
	_twi_send_data(0x52, buffer, 3);
	__twi_wait_ready();

	mute_line = 0;

	mic_mute = 1;
	beep_18 = 0;
	uint8_t tmr_blink = timer_reg();
	update_gpio();

	eeprom_read_block(&sysCfg, (void*) 0x10, sizeof(struct configBlock));
	uint8_t actual_crc = crc8(&sysCfg, sizeof(struct configBlock) - 1);
	if (sysCfg.crc != actual_crc)
	{
		sysCfg.mic_gain_and_pwr = 0x80;
		sysCfg.call_vol = 10;
		sysCfg.sidetone = 0x0f;
	}

	sysCfg.volume = 15;

	//default settings

	update_sidetone();
	update_volume();

	if (sysCfg.crc == actual_crc)
	{
		push_tone(1, 250, 100, 6);
		push_tone(0, 0, 50, 6);
		push_tone(0, 500, 100, 6);
		push_tone(0, 0, 50, 6);
		push_tone(0, 1000, 100, 6);
	}
	else
	{
		push_tone(1, 250, 100, 6);
		push_tone(0, 0, 50, 6);
		push_tone(0, 250, 100, 6);
		push_tone(0, 0, 50, 6);
		push_tone(0, 250, 100, 6);
	}
	__twi_wait_ready();
	buffer[0] = 0x00;
	_twi_send_data(0x40, buffer, 1);
	uint8_t ctr=0;

	uint8_t button_Enc = button_register(btnEncoder);
	uint8_t button_PTT = button_register(btnPTT);
	uint8_t button_Call = button_register(btnCall);
	uint8_t tmr_LastPTT = timer_reg();
	uint8_t ptt_hold=0;
	uint16_t old_systick=0;

	//wait till beep sequence done
	while(tones_queued)
	{
		update_gpio();
		signalling_task();
	}
	while(1) {
		update_gpio();
		signalling_task();
		encoder_task();
		i2c_task();
		if (systick != old_systick)
		{
			old_systick = systick;
			button_proc(button_Enc, (PINC&_BV(5))?0:1);
			button_proc(button_PTT, (front_inp & _BV(5))?0:1);
			button_proc(button_Call, (front_inp & _BV(6))?0:1);
			old_systick = systick;
		}
		uint16_t evt = event_get();
		switch(evt & btnMask)
		{
			case btnEncoder:
			{ //this is a bit more complex....
				switch(menu_level)
				{
					case lvlVolume:
						if (evt & evtDown)
						{
							mute_line = 1 - mute_line;
							push_tone(1, mute_line?400:800, 50, 6);
							push_tone(0,  0, 50, 6);
							push_tone(0, mute_line?400:800, 50, 6);
						}
						if (evt & evtHold)
						{
							mute_line = 0;
							push_tone(1,800, 1000, 10);
							menu_level = lvlSideTone;
							timer_set(tmr_menuEscape, MENU_HOLD_TIME);
						}
						break;
					case lvlSideTone:
						if (evt & evtDown)
						{
							menu_level = lvlMicGain;
							push_tone(1,800, 250, 10);
							timer_set(tmr_menuEscape, MENU_HOLD_TIME);
						}
						break;
					case lvlMicGain:
						if (evt & evtDown)
						{
							menu_level = lvlVolume;
							menu_finish();
						}
						break;
					default:
						menu_level = lvlVolume;
				}
			}
				break;
			case btnPTT:
				if (evt & evtDown)
				{
					mic_mute = 0;
					mute_line = 0;
					if (ptt_hold)
					{
						ptt_hold=0;
						push_tone(1, 400, 50, 6);
					}
					else
					{
						if (!timer_expired(tmr_LastPTT))
						{
							ptt_hold = 1;
							push_tone(1, 800, 150, 6);
						}
					}
					timer_set(tmr_LastPTT, 300);
				}
				break;
			case btnCall:
				if (menu_level != lvlMicGain)
					break;
				if (evt & evtDown)
				{
					timer_set(tmr_menuEscape, MENU_HOLD_TIME);
					sysCfg.mic_gain_and_pwr ^= cfgMicPower;
				}
		}
		if (button_state(button_PTT) || ptt_hold)
		{
			mic_mute = 0;
		}
		else
		{
			if (timer_expired(tmr_LastPTT))
			{
				mic_mute = 1;
			}
		}
		if (menu_level != lvlMicGain)
			call_send = button_state(button_Call);




		uint8_t leds = 0;

		if (timer_expired(tmr_blink))
		{
			update_gpio();
			timer_set(tmr_blink, 125);

			if ((call_sig) && (ctr & 2))
			{
				leds |= frontLedCall;
				if (ctr&1)
					--call_sig;
			}


			switch (menu_level)
			{
				case lvlVolume:
					if ((mute_line == 0) || (ctr&4))
						leds |= frontLED1;
					break;
				case lvlSideTone:
					leds |=frontLED2;
					break;

				case lvlMicGain:
					switch (sysCfg.mic_gain_and_pwr & cfgMicGainMask)
					{
						case 0:
							leds = 0x0f ^ 0x01;
							break;
						case 1:
							leds = 0x0f ^ 0x02;
							break;
						case 2:
							leds = 0x0f ^ 0x04;
							break;
						case 3:
						default:
							leds = 0x0f ^ 0x08;
							break;
					}

					if (ctr&2)
						leds = 0x0f;

					if (sysCfg.mic_gain_and_pwr & cfgMicPower)
						leds|= frontLedCall;
					break;
			}
			if (mic_mute == 0)
				leds |= frontLEDPtt;
			front_out = ~leds;

			if (timer_expired(tmr_menuEscape) && (menu_level!=lvlVolume))
				menu_finish();
			ctr++;
		}
	}
}

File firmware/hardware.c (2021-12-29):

#include <stdint.h>
#include <avr/io.h>
#include <avr/interrupt.h>
#include "hardware.h"
#include "i2c.h"

//system state vars
volatile uint8_t mute_line=1;
volatile uint8_t beep_18=1;
volatile uint8_t call_in=0;
volatile uint8_t call_send=0;
volatile uint8_t call_led=0;
volatile uint8_t mic_mute=0;


const uint8_t sine_tab[] = {0x80, 0x8c, 0x98, 0xa4, 0xb0, 0xbb, 0xc6, 0xd0,
                            0xd9, 0xe2, 0xe9, 0xf0, 0xf5, 0xf9, 0xfc, 0xfe,
                            0xfe, 0xfe, 0xfc, 0xf9, 0xf5, 0xf0, 0xe9, 0xe2,
                            0xd9, 0xd0, 0xc6, 0xbb, 0xb0, 0xa4, 0x98, 0x8c,
                            0x80, 0x73, 0x67, 0x5b, 0x4f, 0x44, 0x39, 0x2f,
                            0x26, 0x1d, 0x16, 0x10, 0x0a, 0x06, 0x03, 0x01,
                            0x01, 0x01, 0x03, 0x06, 0x0a, 0x0f, 0x16, 0x1d,
                            0x26, 0x2f, 0x39, 0x44, 0x4f, 0x5b, 0x67, 0x73};

inline uint8_t sineLookup(uint8_t in) {
	uint8_t v1=0, v2=0;
	uint8_t step = in>>2;
	uint8_t sub=in&3;
	v1 = sine_tab[step++];
	if ((step<sizeof(sine_tab))&&(sub)) {
		uint16_t accu=0;
		v2 = sine_tab[step];
		for (register uint8_t i=0;i<4;++i) {
			if (i<sub)
				accu+=v2;
			else
				accu+=v1;
		}
		accu>>=2;
		v1=accu;
	}
	return v1;
}

struct configBlock sysCfg;

int8_t enc_ctr=0;
volatile uint8_t enc_btn=0;
void update_gpio(void)
{
	if (mute_line)
		PORTB&=~_BV(2);
	else
		PORTB|=_BV(2);

	if (beep_18)
		PORTB|=_BV(1);
	else
		PORTB&=~_BV(1);

	call_in = (PINB & _BV(0))==0;
	enc_btn = (PINC&_BV(5))?0:1;

	if (sysCfg.mic_gain_and_pwr & 0x80)
		PORTC&= ~_BV(3);
	else
		PORTC |= _BV(3);

	if (mic_mute)
		PORTD|= _BV(2);
	else
		PORTD&=~_BV(2);

	switch(sysCfg.mic_gain_and_pwr & cfgMicGainMask)
	{
		case 0:
			PORTD|= _BV(4); // -10 (*)
			PORTD&=~_BV(3); // +20 ( ) -10
			break;
		case 1:
			PORTD&=~_BV(4); // -10 ( )
			PORTD&=~_BV(3); // +20 ( ) 0
			break;
		case 2:
			PORTD|= _BV(4); // -10 (*)
			PORTD|= _BV(3); // +20 (*) +10
			break;
		case 3:
		default:
			PORTD&=~_BV(4); // -10 ( )
			PORTD|= _BV(3); // +20 (*) +20
			break;
	}
	if (call_send)
		PORTA|=_BV(0);
	else
		PORTA&=~_BV(0);
}

void init_beep(void)
{
	//PWM stage 0A on
	TCCR0A = _BV(WGM00) | _BV(WGM01) | _BV(COM0A1);
	TCCR0B = 1;
	OCR0A = 0x80;
}

volatile uint8_t tone_accu=0, tone_vol=0x7f;
volatile uint8_t tone_inc = 0;
volatile uint8_t cycle;
static inline void do_audio(void)
{
	if (tone_inc)
	{
		int16_t tone = sineLookup(tone_accu);
		tone -=128;
		tone *=tone_vol;
		tone/=256;
		tone+=128;

		OCR0A=tone;//(tone_accu&128)?0x80 + tone_vol: 0x80-tone_vol;
		tone_accu+=tone_inc;
	}
	else
	{
		OCR0A=0x80;
	}
}

uint8_t oldPins=0;

ISR(TIMER2_OVF_vect) // 16kHz
{	do_audio();
	uint8_t pins = PINC&0xc0;
	if (oldPins!=pins)
	{
		if (pins == 0x00)
		{
			if (oldPins == 0x80)
				enc_ctr--;
			if (oldPins == 0x40)
				enc_ctr++;
		}
	}
	oldPins = pins;
}

void init_timers(void)
{
	timer_init();
	TCCR2A =  _BV(WGM20) | _BV(WGM21);
	TCCR2B =  _BV(WGM22) | 2;
	OCR2A = 249/2;
	TIMSK2 = _BV(OCIE2A) | _BV(TOIE2);
}

struct tone_task toneQueue[8];
uint8_t tones_queued=0;

void push_tone(uint8_t replace, uint16_t freq, uint16_t duration, uint8_t volume)
{
	if (replace)
		tones_queued=0;
	if (tones_queued == 8)
		tones_queued=7;
	toneQueue[tones_queued].freq = freq;
	toneQueue[tones_queued].duration = duration;
	toneQueue[tones_queued].volume = volume;
	++tones_queued;
}


const uint8_t volumes[6] = {127,  // 0dB
                            90,  // -3dB
                            64,  // -6dB
                            45,  // -9dB
                            32,  // -12dB
                            23   // -15dB
                           };

void beep_setvol(uint8_t volume)
{
	uint8_t tmp = volume;
	if (volume)
	{
		if (tmp>12)
			tmp=12;
		tmp--;
		tone_vol = volumes[5 - (tmp%6)];
		beep_18 = (tmp>5)?0:1;
		update_gpio();
	}
	else
	{
		tone_vol = 0;
	}
}

void update_volume(void)
{
	static uint8_t buffer[2];
	buffer[0] = 0x00 | ((31 - sysCfg.volume) & 0x1f);
	buffer[1] = 0x40 | ((31 - sysCfg.volume) & 0x1f);
	_twi_send_data(0x52, buffer, 2);
	__twi_wait_ready();
}

void update_sidetone( void )
{
	static uint8_t buffer[2];
	buffer[0] = 0x00;
	buffer[1] = sysCfg.sidetone * 0x11;
	_twi_send_data(0x50, buffer, 2);
}

void init_hw(void)
{
	DDRA = 0x09;
	DDRB = 0xde;
	PORTC = 0xe8;
	DDRC = 0x08;
	PORTD = 0x04;
	DDRD = 0x3e;
	SPCR0 = _BV(SPE0)|_BV(MSTR0)|_BV(SPR00)|_BV(DORD0);
}

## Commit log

2021-12-29 added hardware
    [beltpack_v1.brd, beltpack_v1.sch, beltpack_v1_fixed.brd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]
2021-12-30 added PDF schematics
    [beltpack_v1_fixed.brd]
2022-01-01 circuit description

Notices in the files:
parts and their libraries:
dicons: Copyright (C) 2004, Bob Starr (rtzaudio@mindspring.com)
